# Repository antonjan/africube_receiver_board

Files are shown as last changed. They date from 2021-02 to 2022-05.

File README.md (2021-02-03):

this is an Software Define Radio receiver PCB project base on msi2500 and msi001. use kicad to view it

这是一个基于msi2500 和 msi001的软件无线电PCB工程项目， 使用kiCAD浏览此工程

如果需要PCB打样，把gerber目录下的文件发给PCB加工厂即可

Send gerbar files to PCB factory . you'd better to use SMT

建议叫工厂SMT贴片，手动焊接容易太多bug

软件使用SDRuno（选SDRPlay）

software compatible with SDRplay

使用效果

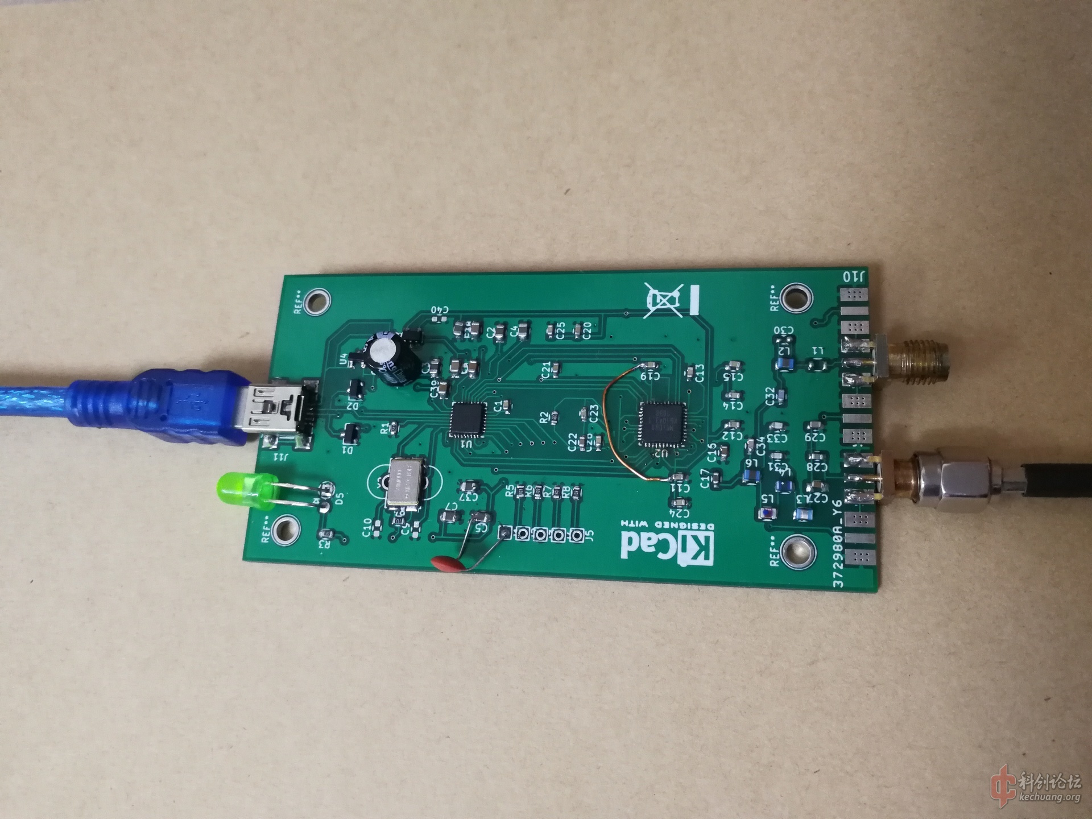
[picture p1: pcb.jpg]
PCB


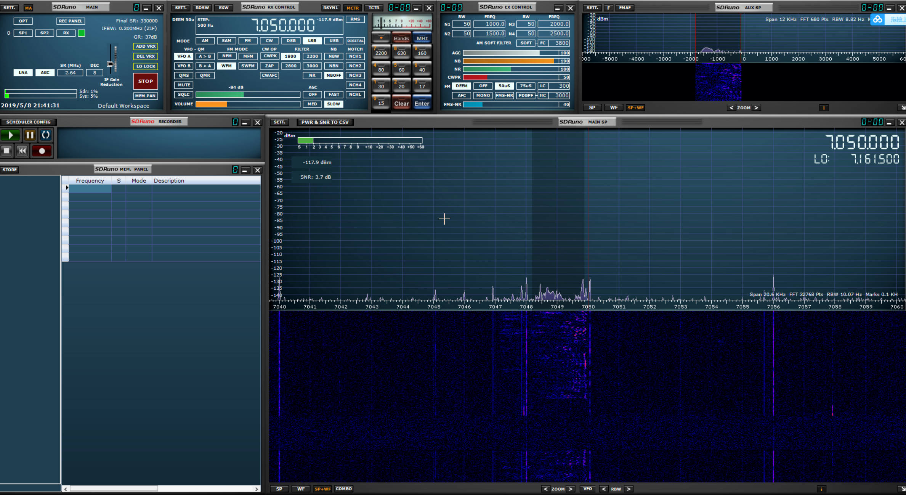
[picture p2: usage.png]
SDR


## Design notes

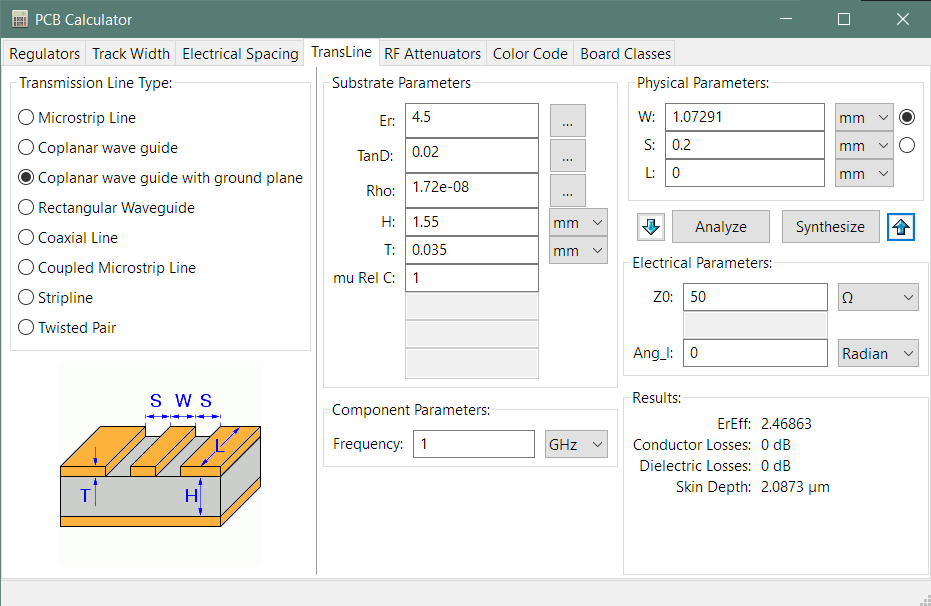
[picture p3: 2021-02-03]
msiSDR-master/Docs/Screenshot 2021-01-29 152604.png

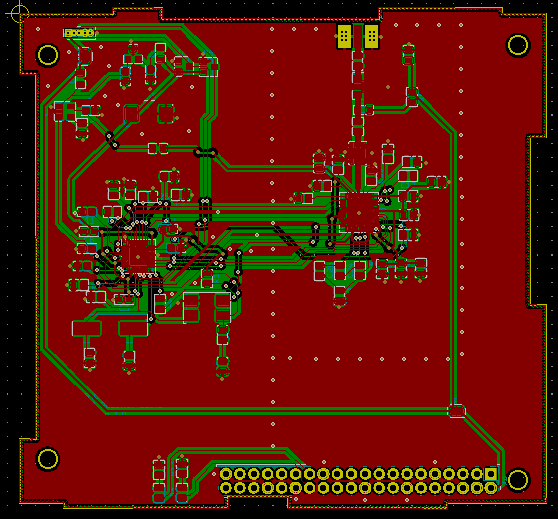
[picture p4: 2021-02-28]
Africube_rx_boards_1.png

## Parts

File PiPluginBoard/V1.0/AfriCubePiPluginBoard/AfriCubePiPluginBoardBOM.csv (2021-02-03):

Source: | F:\AfriCube\PiPluginBoard\V1.0\AfriCubePiPluginBoard\AfriCubePiPluginBoard.sch
Date: | 2020/02/01 08:34
Tool: | Eeschema (5.1.2)-2
Generator: | C:\Program Files\KiCad\bin\scripting\plugins/bom_csv_grouped_by_value.py
Component Count: | 58
Individual Components:
Item | Qty | Reference(s) | Value | LibPart | Footprint |  |  |  |  | Datasheet
 |  | BT1 | Battery_Cell_3V | Device:Battery_Cell | Battery:BatteryHolder_Keystone_3000_1x12mm |  |  |  |  | ~
 |  | C1 | 47uF | Device:C | Resistor_SMD:R_1210_3225Metric_Pad1.42x2.65mm_HandSolder |  |  |  |  | ~
 |  | C2 | 100nF | Device:C | Resistor_SMD:R_0805_2012Metric_Pad1.15x1.40mm_HandSolder |  |  |  |  | ~
 |  | C3 | 10uF | Device:C | Resistor_SMD:R_0805_2012Metric_Pad1.15x1.40mm_HandSolder |  |  |  |  | ~
 |  | C4 | 100nF | Device:C | Resistor_SMD:R_0805_2012Metric_Pad1.15x1.40mm_HandSolder |  |  |  |  | ~
 |  | C5 | 4.7uF | Device:C | Resistor_SMD:R_0805_2012Metric_Pad1.15x1.40mm_HandSolder |  |  |  |  | ~
 |  | C6 | 47uF | Device:C | Resistor_SMD:R_1210_3225Metric_Pad1.42x2.65mm_HandSolder |  |  |  |  | ~
 |  | C7 | 47uF | Device:C | Resistor_SMD:R_1210_3225Metric_Pad1.42x2.65mm_HandSolder |  |  |  |  | ~
 |  | C8 | 10uF | Device:C | Resistor_SMD:R_0805_2012Metric_Pad1.15x1.40mm_HandSolder |  |  |  |  | ~
 |  | C9 | 1uF | Device:C | Resistor_SMD:R_0805_2012Metric_Pad1.15x1.40mm_HandSolder |  |  |  |  | ~
 |  | C10 | 10uF | Device:C | Resistor_SMD:R_0805_2012Metric_Pad1.15x1.40mm_HandSolder |  |  |  |  | ~
 |  | C11 | 100nF | Device:C | Resistor_SMD:R_0805_2012Metric_Pad1.15x1.40mm_HandSolder |  |  |  |  | ~
 |  | C12 | 10uF | Device:C | Resistor_SMD:R_0805_2012Metric_Pad1.15x1.40mm_HandSolder |  |  |  |  | ~
 |  | C13 | 100nF | Device:C | Resistor_SMD:R_0805_2012Metric_Pad1.15x1.40mm_HandSolder |  |  |  |  | ~
 |  | C14 | 100nF | Device:C | Resistor_SMD:R_0805_2012Metric_Pad1.15x1.40mm_HandSolder |  |  |  |  | ~
 |  | D1 | LED | Device:LED | Resistor_SMD:R_0805_2012Metric_Pad1.15x1.40mm_HandSolder |  |  |  |  | ~
 |  | D2 | LED | Device:LED | Resistor_SMD:R_0805_2012Metric_Pad1.15x1.40mm_HandSolder |  |  |  |  | ~
 |  | D3 | BAV99 | Diode:BAV99 | Package_TO_SOT_SMD:SOT-23 |  |  |  |  | https://assets.nexperia.com/documents/data-sheet/BAV99_SER.pdf
 |  | D4 | BAV99 | Diode:BAV99 | Package_TO_SOT_SMD:SOT-23 |  |  |  |  | https://assets.nexperia.com/documents/data-sheet/BAV99_SER.pdf
 |  | J1 | USB_A | Connector:USB_A | Connector_PinHeader_1.00mm:PinHeader_1x05_P1.00mm_Vertical |  |  |  |  | ~
 |  | J2 | SD_Card | Connector:SD_Card | Connector_Card:microSD_HC_Hirose_DM3D-SF |  |  |  |  | http://portal.fciconnect.com/Comergent//fci/drawing/10067847.pdf
 |  | J3 | USB_B_Mini | Connector:USB_B_Mini | Connector_USB:USB_Mini-B_Lumberg_2486_01_Horizontal |  |  |  |  | ~
 |  | J4 | SODIMM-200 | Connector:SODIMM-200 | RaspberryPi:Conn_TE-DDR2-SODIMM-0.6-200P-doublesided
 |  | J5 | Barrel_Jack_MountingPin | Connector:Barrel_Jack_MountingPin | Connector_BarrelJack:BarrelJack_Wuerth_6941xx301002 |  |  |  |  | ~
 |  | J6 | Raspberry_Pi_2_3 | Connector:Raspberry_Pi_2_3 | Connector_PinHeader_2.54mm:PinHeader_2x20_P2.54mm_Vertical |  |  |  |  | https://www.raspberrypi.org/documentation/hardware/raspberrypi/schematics/rpi_SCH_3bplus_1p0_reduced.pdf
 |  | J7 | Conn_01x04_Male | Connector:Conn_01x04_Male | Connector_PinSocket_2.54mm:PinSocket_1x04_P2.54mm_Vertical |  |  |  |  | ~
 |  | JP1 | Jumper_Boot_Select | Jumper:Jumper_3_Open | Connector_PinSocket_2.54mm:PinSocket_1x03_P2.54mm_Vertical |  |  |  |  | ~
 |  | JP2 | WDT_S0 | Jumper:SolderJumper_3_Open | Jumper:SolderJumper-3_P1.3mm_Open_RoundedPad1.0x1.5mm |  |  |  |  | ~
 |  | JP3 | WDT_S1 | Jumper:SolderJumper_3_Open | Jumper:SolderJumper-3_P1.3mm_Open_RoundedPad1.0x1.5mm |  |  |  |  | ~
 |  | JP4 | WDT_S2 | Jumper:SolderJumper_3_Open | Jumper:SolderJumper-3_P1.3mm_Open_RoundedPad1.0x1.5mm |  |  |  |  | ~
 |  | P1 | PC104 | AfriCubePiPluginBoard-rescue:PC104-PC104 | PC104B:PC104
 |  | Q1 | BSS138 | Transistor_FET:BSS138 | Package_TO_SOT_SMD:SOT-23 |  |  |  |  | https://www.fairchildsemi.com/datasheets/BS/BSS138.pdf
 |  | Q2 | BSS138 | Transistor_FET:BSS138 | Package_TO_SOT_SMD:SOT-23 |  |  |  |  | https://www.fairchildsemi.com/datasheets/BS/BSS138.pdf
 |  | Q3 | BSS138 | Transistor_FET:BSS138 | Package_TO_SOT_SMD:SOT-23 |  |  |  |  | https://www.fairchildsemi.com/datasheets/BS/BSS138.pdf
 |  | R1 | 47K | Device:R | Resistor_SMD:R_0805_2012Metric_Pad1.15x1.40mm_HandSolder |  |  |  |  | ~
 |  | R2 | 470R | Device:R | Resistor_SMD:R_0805_2012Metric_Pad1.15x1.40mm_HandSolder |  |  |  |  | ~
 |  | R3 | 47K | Device:R | Resistor_SMD:R_0805_2012Metric_Pad1.15x1.40mm_HandSolder |  |  |  |  | ~
 |  | R4 | 100K | Device:R | Resistor_SMD:R_0805_2012Metric_Pad1.15x1.40mm_HandSolder |  |  |  |  | ~
 |  | R5 | 100K | Device:R | Resistor_SMD:R_0805_2012Metric_Pad1.15x1.40mm_HandSolder |  |  |  |  | ~
 |  | R6 | 47K | Device:R | Resistor_SMD:R_0805_2012Metric_Pad1.15x1.40mm_HandSolder |  |  |  |  | ~
 |  | R7 | 470R | Device:R | Resistor_SMD:R_0805_2012Metric_Pad1.15x1.40mm_HandSolder |  |  |  |  | ~
 |  | R8 | 100K | Device:R | Resistor_SMD:R_0805_2012Metric_Pad1.15x1.40mm_HandSolder |  |  |  |  | ~
 |  | R9 | 100K | Device:R | Resistor_SMD:R_0805_2012Metric_Pad1.15x1.40mm_HandSolder |  |  |  |  | ~
 |  | R10 | 100K | Device:R | Resistor_SMD:R_0805_2012Metric_Pad1.15x1.40mm_HandSolder |  |  |  |  | ~
 |  | R11 | 100K | Device:R | Resistor_SMD:R_0805_2012Metric_Pad1.15x1.40mm_HandSolder |  |  |  |  | ~
 |  | R12 | 4K7 | Device:R | Resistor_SMD:R_0805_2012Metric_Pad1.15x1.40mm_HandSolder |  |  |  |  | ~
 |  | R13 | 4K7 | Device:R | Resistor_SMD:R_0805_2012Metric_Pad1.15x1.40mm_HandSolder |  |  |  |  | ~
 |  | R14 | 100K | Device:R | Resistor_SMD:R_0805_2012Metric_Pad1.15x1.40mm_HandSolder |  |  |  |  | ~
 |  | R15 | 100K | Device:R | Resistor_SMD:R_0805_2012Metric_Pad1.15x1.40mm_HandSolder |  |  |  |  | ~
 |  | R16 | 100K | Device:R | Resistor_SMD:R_0805_2012Metric_Pad1.15x1.40mm_HandSolder |  |  |  |  | ~
 |  | R17 | 270R | Device:R | Resistor_SMD:R_0805_2012Metric_Pad1.15x1.40mm_HandSolder |  |  |  |  | ~
 |  | R18 | 150R | Device:R | Resistor_SMD:R_0805_2012Metric_Pad1.15x1.40mm_HandSolder |  |  |  |  | ~
 |  | R19 | 270R | Device:R | Resistor_SMD:R_0805_2012Metric_Pad1.15x1.40mm_HandSolder |  |  |  |  | ~
 |  | R20 | 150R | Device:R | Resistor_SMD:R_0805_2012Metric_Pad1.15x1.40mm_HandSolder |  |  |  |  | ~
 |  | U1 | FSUSB42MUX | AfriCubePiPluginBoard-rescue:FSUSB42MUX-FSUSB42MUX | Package_SO:MSOP-10_3x3mm_P0.5mm
 |  | U2 | TLV70218_SOT23-5 | Regulator_Linear:TLV70218_SOT23-5 | Package_TO_SOT_SMD:SOT-23-5 |  |  |  |  | http://www.ti.com/lit/ds/symlink/tlv702.pdf
 |  | U3 | MAX6373 | Power_Supervisor:MAX6373 | Package_TO_SOT_SMD:SOT-23-8 |  |  |  |  | https://datasheets.maximintegrated.com/en/ds/MAX6369-MAX6374.pdf
 |  | U4 | DS3231M | Timer_RTC:DS3231M | Package_SO:SOIC-16W_7.5x10.3mm_P1.27mm |  |  |  |  | http://datasheets.maximintegrated.com/en/ds/DS3231.pdf
Collated Components:
Item | Qty | Reference(s) | Value | LibPart | Footprint | Req | Have | Ordered from RS | RS part nr | Datasheet
1 | 1 | BT1 | Battery_Cell_3V | Device:Battery_Cell | Battery:BatteryHolder_Keystone_3000_1x12mm | 3 | 0 | 5 | 219-7926 | ~
2 | 3 | C1, C6, C7 | 47uF (max 5V) | Device:C | Resistor_SMD:R_1210_3225Metric_Pad1.42x2.65mm_HandSolder | 9 | 1 | 10 | 788-3029/891-9817 | ~
3 | 5 | C2, C4, C11, C13, C14 | 100nF | Device:C | Resistor_SMD:R_0805_2012Metric_Pad1.15x1.40mm_HandSolder | 15 | 25 | 0 | 264-4416 | ~
4 | 4 | C3, C8, C10, C12 | 10uF (1xmax13.5V, others max 3V3) | Device:C | Resistor_SMD:R_0805_2012Metric_Pad1.15x1.40mm_HandSolder | 12 | 25+ | 0 | 723-6039 | ~
5 | 1 | C5 | 4.7uF (max 3v3) | Device:C | Resistor_SMD:R_0805_2012Metric_Pad1.15x1.40mm_HandSolder | 3 | 0 | 10 | 152-6136 | ~
6 | 1 | C9 | 1uF (max 3V) | Device:C | Resistor_SMD:R_0805_2012Metric_Pad1.15x1.40mm_HandSolder | 3 | 10 | 0 | 451-5770 | ~
7 | 2 | D1, D2 | LED | Device:LED | Resistor_SMD:R_0805_2012Metric_Pad1.15x1.40mm_HandSolder | 6 |  |  |  | ~
8 | 2 | D3, D4 | BAV99 | Diode:BAV99 | Package_TO_SOT_SMD:SOT-23 | 6 |  |  |  | https://assets.nexperia.com/documents/data-sheet/BAV99_SER.pdf
9 | 1 | J1 | USB_A | Connector:USB_A | Connector_PinHeader_1.00mm:PinHeader_1x05_P1.00mm_Vertical | 3 |  |  |  | ~
10 | 1 | J2 | SD_Card | Connector:SD_Card | Connector_Card:microSD_HC_Hirose_DM3D-SF | 3 |  |  |  | http://portal.fciconnect.com/Comergent//fci/drawing/10067847.pdf
11 | 1 | J3 | USB_B_Mini | Connector:USB_B_Mini | Connector_USB:USB_Mini-B_Lumberg_2486_01_Horizontal | 3 |  |  |  | ~
12 | 1 | J4 | SODIMM-200 | Connector:SODIMM-200 | RaspberryPi:Conn_TE-DDR2-SODIMM-0.6-200P-doublesided | 3
13 | 1 | J5 | Barrel_Jack_MountingPin | Connector:Barrel_Jack_MountingPin | Connector_BarrelJack:BarrelJack_Wuerth_6941xx301002 | 3 | 0 | 5 |  | ~
14 | 1 | J6 | Raspberry_Pi_2_3 | Connector:Raspberry_Pi_2_3 | Connector_PinHeader_2.54mm:PinHeader_2x20_P2.54mm_Vertical | 3 | 0 |  |  | https://www.raspberrypi.org/documentation/hardware/raspberrypi/schematics/rpi_SCH_3bplus_1p0_reduced.pdf
15 | 1 | J7 | Conn_01x04_Male | Connector:Conn_01x04_Male | Connector_PinSocket_2.54mm:PinSocket_1x04_P2.54mm_Vertical | 3 | many | 0 |  | ~
16 | 1 | JP1 | Jumper_Boot_Select | Jumper:Jumper_3_Open | Connector_PinSocket_2.54mm:PinSocket_1x03_P2.54mm_Vertical | 3 | many | 0 |  | ~
17 | 1 | JP2 | WDT_S0 | Jumper:SolderJumper_3_Open | Jumper:SolderJumper-3_P1.3mm_Open_RoundedPad1.0x1.5mm | 3 | NR |  |  | ~
18 | 1 | JP3 | WDT_S1 | Jumper:SolderJumper_3_Open | Jumper:SolderJumper-3_P1.3mm_Open_RoundedPad1.0x1.5mm | 3 | NR |  |  | ~
19 | 1 | JP4 | WDT_S2 | Jumper:SolderJumper_3_Open | Jumper:SolderJumper-3_P1.3mm_Open_RoundedPad1.0x1.5mm | 3 | NR |  |  | ~
20 | 1 | P1 | PC104 | AfriCubePiPluginBoard-rescue:PC104-PC104 | PC104B:PC104 | 3 | 2.5
21 | 3 | Q1, Q2, Q3 | BSS138 | Transistor_FET:BSS138 | Package_TO_SOT_SMD:SOT-23 | 9 |  |  |  | https://www.fairchildsemi.com/datasheets/BS/BSS138.pdf
22 | 3 | R1, R3, R6 | 47K | Device:R | Resistor_SMD:R_0805_2012Metric_Pad1.15x1.40mm_HandSolder | 9 |  |  |  | ~
23 | 2 | R2, R7 | 470R | Device:R | Resistor_SMD:R_0805_2012Metric_Pad1.15x1.40mm_HandSolder | 6 |  |  |  | ~
24 | 9 | R4, R5, R8, R9, R10, R11, R14, R15, R16 | 100K | Device:R | Resistor_SMD:R_0805_2012Metric_Pad1.15x1.40mm_HandSolder | 27 |  |  |  | ~
25 | 2 | R12, R13 | 4K7 | Device:R | Resistor_SMD:R_0805_2012Metric_Pad1.15x1.40mm_HandSolder | 6 |  |  |  | ~
26 | 2 | R17, R19 | 270R | Device:R | Resistor_SMD:R_0805_2012Metric_Pad1.15x1.40mm_HandSolder | 6 |  |  |  | ~
27 | 2 | R18, R20 | 150R | Device:R | Resistor_SMD:R_0805_2012Metric_Pad1.15x1.40mm_HandSolder | 6 |  |  |  | ~
28 | 1 | U1 | FSUSB42MUX | AfriCubePiPluginBoard-rescue:FSUSB42MUX-FSUSB42MUX | Package_SO:MSOP-10_3x3mm_P0.5mm | 3 | 0 | 3
29 | 1 | U2 | TLV70218_SOT23-5 | Regulator_Linear:TLV70218_SOT23-5 | Package_TO_SOT_SMD:SOT-23-5 | 3 |  |  |  | http://www.ti.com/lit/ds/symlink/tlv702.pdf
30 | 1 | U3 | MAX6373 | Power_Supervisor:MAX6373 | Package_TO_SOT_SMD:SOT-23-8 | 3 |  |  |  | https://datasheets.maximintegrated.com/en/ds/MAX6369-MAX6374.pdf
31 | 1 | U4 | DS3231M | Timer_RTC:DS3231M | Package_SO:SOIC-16W_7.5x10.3mm_P1.27mm | 3 |  |  |  | http://datasheets.maximintegrated.com/en/ds/DS3231.pdf

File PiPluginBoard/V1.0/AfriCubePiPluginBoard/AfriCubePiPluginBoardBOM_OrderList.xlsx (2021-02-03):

Source: | F:\AfriCube\PiPluginBoard\V1.0\AfriCubePiPluginBoard\AfriCubePiPluginBoard.sch
Date: | 2020-02-01 08:34
Tool: | Eeschema (5.1.2)-2
Generator: | C:\Program Files\KiCad\bin\scripting\plugins/bom_csv_grouped_by_value.py
Component Count: | 58
Individual Components:
Item | Qty | Reference(s) | Value | LibPart | Footprint |  |  |  |  | Datasheet
 |  | BT1 | Battery_Cell_3V | Device:Battery_Cell | Battery:BatteryHolder_Keystone_3000_1x12mm |  |  |  |  | ~
 |  | C1 | 47uF | Device:C | Resistor_SMD:R_1210_3225Metric_Pad1.42x2.65mm_HandSolder |  |  |  |  | ~
 |  | C2 | 100nF | Device:C | Resistor_SMD:R_0805_2012Metric_Pad1.15x1.40mm_HandSolder |  |  |  |  | ~
 |  | C3 | 10uF | Device:C | Resistor_SMD:R_0805_2012Metric_Pad1.15x1.40mm_HandSolder |  |  |  |  | ~
 |  | C4 | 100nF | Device:C | Resistor_SMD:R_0805_2012Metric_Pad1.15x1.40mm_HandSolder |  |  |  |  | ~
 |  | C5 | 4.7uF | Device:C | Resistor_SMD:R_0805_2012Metric_Pad1.15x1.40mm_HandSolder |  |  |  |  | ~
 |  | C6 | 47uF | Device:C | Resistor_SMD:R_1210_3225Metric_Pad1.42x2.65mm_HandSolder |  |  |  |  | ~
 |  | C7 | 47uF | Device:C | Resistor_SMD:R_1210_3225Metric_Pad1.42x2.65mm_HandSolder |  |  |  |  | ~
 |  | C8 | 10uF | Device:C | Resistor_SMD:R_0805_2012Metric_Pad1.15x1.40mm_HandSolder |  |  |  |  | ~
 |  | C9 | 1uF | Device:C | Resistor_SMD:R_0805_2012Metric_Pad1.15x1.40mm_HandSolder |  |  |  |  | ~
 |  | C10 | 10uF | Device:C | Resistor_SMD:R_0805_2012Metric_Pad1.15x1.40mm_HandSolder |  |  |  |  | ~
 |  | C11 | 100nF | Device:C | Resistor_SMD:R_0805_2012Metric_Pad1.15x1.40mm_HandSolder |  |  |  |  | ~
 |  | C12 | 10uF | Device:C | Resistor_SMD:R_0805_2012Metric_Pad1.15x1.40mm_HandSolder |  |  |  |  | ~
 |  | C13 | 100nF | Device:C | Resistor_SMD:R_0805_2012Metric_Pad1.15x1.40mm_HandSolder |  |  |  |  | ~
 |  | C14 | 100nF | Device:C | Resistor_SMD:R_0805_2012Metric_Pad1.15x1.40mm_HandSolder |  |  |  |  | ~
 |  | D1 | LED | Device:LED | Resistor_SMD:R_0805_2012Metric_Pad1.15x1.40mm_HandSolder |  |  |  |  | ~
 |  | D2 | LED | Device:LED | Resistor_SMD:R_0805_2012Metric_Pad1.15x1.40mm_HandSolder |  |  |  |  | ~
 |  | D3 | BAV99 | Diode:BAV99 | Package_TO_SOT_SMD:SOT-23 |  |  |  |  | https://assets.nexperia.com/documents/data-sheet/BAV99_SER.pdf
 |  | D4 | BAV99 | Diode:BAV99 | Package_TO_SOT_SMD:SOT-23 |  |  |  |  | https://assets.nexperia.com/documents/data-sheet/BAV99_SER.pdf
 |  | J1 | USB_A | Connector:USB_A | Connector_PinHeader_1.00mm:PinHeader_1x05_P1.00mm_Vertical |  |  |  |  | ~
 |  | J2 | SD_Card | Connector:SD_Card | Connector_Card:microSD_HC_Hirose_DM3D-SF |  |  |  |  | http://portal.fciconnect.com/Comergent//fci/drawing/10067847.pdf
 |  | J3 | USB_B_Mini | Connector:USB_B_Mini | Connector_USB:USB_Mini-B_Lumberg_2486_01_Horizontal |  |  |  |  | ~
 |  | J4 | SODIMM-200 | Connector:SODIMM-200 | RaspberryPi:Conn_TE-DDR2-SODIMM-0.6-200P-doublesided
 |  | J5 | Barrel_Jack_MountingPin | Connector:Barrel_Jack_MountingPin | Connector_BarrelJack:BarrelJack_Wuerth_6941xx301002 |  |  |  |  | ~
 |  | J6 | Raspberry_Pi_2_3 | Connector:Raspberry_Pi_2_3 | Connector_PinHeader_2.54mm:PinHeader_2x20_P2.54mm_Vertical |  |  |  |  | https://www.raspberrypi.org/documentation/hardware/raspberrypi/schematics/rpi_SCH_3bplus_1p0_reduced.pdf
 |  | J7 | Conn_01x04_Male | Connector:Conn_01x04_Male | Connector_PinSocket_2.54mm:PinSocket_1x04_P2.54mm_Vertical |  |  |  |  | ~
 |  | JP1 | Jumper_Boot_Select | Jumper:Jumper_3_Open | Connector_PinSocket_2.54mm:PinSocket_1x03_P2.54mm_Vertical |  |  |  |  | ~
 |  | JP2 | WDT_S0 | Jumper:SolderJumper_3_Open | Jumper:SolderJumper-3_P1.3mm_Open_RoundedPad1.0x1.5mm |  |  |  |  | ~
 |  | JP3 | WDT_S1 | Jumper:SolderJumper_3_Open | Jumper:SolderJumper-3_P1.3mm_Open_RoundedPad1.0x1.5mm |  |  |  |  | ~
 |  | JP4 | WDT_S2 | Jumper:SolderJumper_3_Open | Jumper:SolderJumper-3_P1.3mm_Open_RoundedPad1.0x1.5mm |  |  |  |  | ~
 |  | P1 | PC104 | AfriCubePiPluginBoard-rescue:PC104-PC104 | PC104B:PC104
 |  | Q1 | BSS138 | Transistor_FET:BSS138 | Package_TO_SOT_SMD:SOT-23 |  |  |  |  | https://www.fairchildsemi.com/datasheets/BS/BSS138.pdf
 |  | Q2 | BSS138 | Transistor_FET:BSS138 | Package_TO_SOT_SMD:SOT-23 |  |  |  |  | https://www.fairchildsemi.com/datasheets/BS/BSS138.pdf
 |  | Q3 | BSS138 | Transistor_FET:BSS138 | Package_TO_SOT_SMD:SOT-23 |  |  |  |  | https://www.fairchildsemi.com/datasheets/BS/BSS138.pdf
 |  | R 1 | 47K | Device:R | Resistor_SMD:R_0805_2012Metric_Pad1.15x1.40mm_HandSolder |  |  |  |  | ~
 |  | R 2 | 470R | Device:R | Resistor_SMD:R_0805_2012Metric_Pad1.15x1.40mm_HandSolder |  |  |  |  | ~
 |  | R 3 | 47K | Device:R | Resistor_SMD:R_0805_2012Metric_Pad1.15x1.40mm_HandSolder |  |  |  |  | ~
 |  | R 4 | 100K | Device:R | Resistor_SMD:R_0805_2012Metric_Pad1.15x1.40mm_HandSolder |  |  |  |  | ~
 |  | R 5 | 100K | Device:R | Resistor_SMD:R_0805_2012Metric_Pad1.15x1.40mm_HandSolder |  |  |  |  | ~
 |  | R 6 | 47K | Device:R | Resistor_SMD:R_0805_2012Metric_Pad1.15x1.40mm_HandSolder |  |  |  |  | ~
 |  | R 7 | 470R | Device:R | Resistor_SMD:R_0805_2012Metric_Pad1.15x1.40mm_HandSolder |  |  |  |  | ~
 |  | R 8 | 100K | Device:R | Resistor_SMD:R_0805_2012Metric_Pad1.15x1.40mm_HandSolder |  |  |  |  | ~
 |  | R 9 | 100K | Device:R | Resistor_SMD:R_0805_2012Metric_Pad1.15x1.40mm_HandSolder |  |  |  |  | ~
 |  | R 10 | 100K | Device:R | Resistor_SMD:R_0805_2012Metric_Pad1.15x1.40mm_HandSolder |  |  |  |  | ~
 |  | R 11 | 100K | Device:R | Resistor_SMD:R_0805_2012Metric_Pad1.15x1.40mm_HandSolder |  |  |  |  | ~
 |  | R 12 | 4K7 | Device:R | Resistor_SMD:R_0805_2012Metric_Pad1.15x1.40mm_HandSolder |  |  |  |  | ~
 |  | R 13 | 4K7 | Device:R | Resistor_SMD:R_0805_2012Metric_Pad1.15x1.40mm_HandSolder |  |  |  |  | ~
 |  | R 14 | 100K | Device:R | Resistor_SMD:R_0805_2012Metric_Pad1.15x1.40mm_HandSolder |  |  |  |  | ~
 |  | R 15 | 100K | Device:R | Resistor_SMD:R_0805_2012Metric_Pad1.15x1.40mm_HandSolder |  |  |  |  | ~
 |  | R 16 | 100K | Device:R | Resistor_SMD:R_0805_2012Metric_Pad1.15x1.40mm_HandSolder |  |  |  |  | ~
 |  | R 17 | 270R | Device:R | Resistor_SMD:R_0805_2012Metric_Pad1.15x1.40mm_HandSolder |  |  |  |  | ~
 |  | R 18 | 150R | Device:R | Resistor_SMD:R_0805_2012Metric_Pad1.15x1.40mm_HandSolder |  |  |  |  | ~
 |  | R 19 | 270R | Device:R | Resistor_SMD:R_0805_2012Metric_Pad1.15x1.40mm_HandSolder |  |  |  |  | ~
 |  | R 20 | 150R | Device:R | Resistor_SMD:R_0805_2012Metric_Pad1.15x1.40mm_HandSolder |  |  |  |  | ~
 |  | U1 | FSUSB42MUX | AfriCubePiPluginBoard-rescue:FSUSB42MUX-FSUSB42MUX | Package_SO:MSOP-10_3x3mm_P0.5mm
 |  | U2 | TLV70218_SOT23-5 | Regulator_Linear:TLV70218_SOT23-5 | Package_TO_SOT_SMD:SOT-23-5 |  |  |  |  | http://www.ti.com/lit/ds/symlink/tlv702.pdf
 |  | U3 | MAX6373 | Power_Supervisor:MAX6373 | Package_TO_SOT_SMD:SOT-23-8 |  |  |  |  | https://datasheets.maximintegrated.com/en/ds/MAX6369-MAX6374.pdf
 |  | U4 | DS3231M | Timer_RTC:DS3231M | Package_SO:SOIC-16W_7.5x10.3mm_P1.27mm |  |  |  |  | http://datasheets.maximintegrated.com/en/ds/DS3231.pdf
Collated Components:
Item | Qty | Reference(s) | Value | LibPart | Footprint | Req | Have | Ordered from RS | RS part nr | Datasheet
1 | 1 | BT1 | Battery_Cell_3V | Device:Battery_Cell | Battery:BatteryHolder_Keystone_3000_1x12mm | 3 | 0 | 5 | 219-7926 | ~
2 | 3 | C1, C6, C7 | 47uF (max 5V) | Device:C | Resistor_SMD:R_1210_3225Metric_Pad1.42x2.65mm_HandSolder | 9 | 1 | 10 | 788-3029/891-9817 | ~
3 | 5 | C2, C4, C11, C13, C14 | 100nF | Device:C | Resistor_SMD:R_0805_2012Metric_Pad1.15x1.40mm_HandSolder | 15 | 25 | 0 | 264-4416 | ~
4 | 4 | C3, C8, C10, C12 | 10uF (1xmax13.5V, others max 3V3) | Device:C | Resistor_SMD:R_0805_2012Metric_Pad1.15x1.40mm_HandSolder | 12 | 25+ | 0 | 723-6039 | ~
5 | 1 | C5 | 4.7uF (max 3v3) | Device:C | Resistor_SMD:R_0805_2012Metric_Pad1.15x1.40mm_HandSolder | 3 | 0 | 10 | 152-6136 | ~
6 | 1 | C9 | 1uF (max 3V) | Device:C | Resistor_SMD:R_0805_2012Metric_Pad1.15x1.40mm_HandSolder | 3 | 10 | 0 | 451-5770 | ~
7 | 2 | D1, D2 | LED | Device:LED | Resistor_SMD:R_0805_2012Metric_Pad1.15x1.40mm_HandSolder | 6 | many | 0 | 692-0929 | ~
8 | 2 | D3, D4 | BAV99 | Diode:BAV99 | Package_TO_SOT_SMD:SOT-23 | 6 | 0 | 25 | 690-0016 | https://assets.nexperia.com/documents/data-sheet/BAV99_SER.pdf
9 | 1 | J1 | USB_A | Connector:USB_A | Connector_PinHeader_1.00mm:PinHeader_1x05_P1.00mm_Vertical | 3 | many | 0 |  | ~
10 | 1 | J2 | SD_Card | Connector:SD_Card | Connector_Card:microSD_HC_Hirose_DM3D-SF | 3 | 0 | 5 | 738-8809 | http://portal.fciconnect.com/Comergent//fci/drawing/10067847.pdf
11 | 1 | J3 | USB_B_Mini | Connector:USB_B_Mini | Connector_USB:USB_Mini-B_Lumberg_2486_01_Horizontal | 3 | 0 | 5 | 666-1099 | ~
12 | 1 | J4 | SODIMM-200 | Connector:SODIMM-200 | RaspberryPi:Conn_TE-DDR2-SODIMM-0.6-200P-doublesided | 3 | 4 | 0 (combine 12x2s ) | 670-3500
13 | 1 | J5 | Barrel_Jack_MountingPin | Connector:Barrel_Jack_MountingPin | Connector_BarrelJack:BarrelJack_Wuerth_6941xx301002 | 3 | 0 | 5 | 122-4879 | ~
14 | 1 | J6 | Raspberry_Pi_2_3 | Connector:Raspberry_Pi_2_3 | Connector_PinHeader_2.54mm:PinHeader_2x20_P2.54mm_Vertical | 3 | 0 | 5 | 670-3496 | https://www.raspberrypi.org/documentation/hardware/raspberrypi/schematics/rpi_SCH_3bplus_1p0_reduced.pdf
15 | 1 | J7 | Conn_01x04_Male | Connector:Conn_01x04_Male | Connector_PinSocket_2.54mm:PinSocket_1x04_P2.54mm_Vertical | 3 | many | 0 |  | ~
16 | 1 | JP1 | Jumper_Boot_Select | Jumper:Jumper_3_Open | Connector_PinSocket_2.54mm:PinSocket_1x03_P2.54mm_Vertical | 3 | many | 0 |  | ~
17 | 1 | JP2 | WDT_S0 | Jumper:SolderJumper_3_Open | Jumper:SolderJumper-3_P1.3mm_Open_RoundedPad1.0x1.5mm | 3 | NR | 0 |  | ~
18 | 1 | JP3 | WDT_S1 | Jumper:SolderJumper_3_Open | Jumper:SolderJumper-3_P1.3mm_Open_RoundedPad1.0x1.5mm | 3 | NR | 0 |  | ~
19 | 1 | JP4 | WDT_S2 | Jumper:SolderJumper_3_Open | Jumper:SolderJumper-3_P1.3mm_Open_RoundedPad1.0x1.5mm | 3 | NR | 0 |  | ~
20 | 1 | P1 | PC104 | AfriCubePiPluginBoard-rescue:PC104-PC104 | PC104B:PC104 | 3 | 2.5 | 1 short!
21 | 3 | Q1, Q2, Q3 | BSS138 | Transistor_FET:BSS138 | Package_TO_SOT_SMD:SOT-23 | 9 | 5 | 10 | 671-0324 | https://www.fairchildsemi.com/datasheets/BS/BSS138.pdf
22 | 3 | R1, R3, R6 | 47K | Device:R | Resistor_SMD:R_0805_2012Metric_Pad1.15x1.40mm_HandSolder | 9 | 0 | 50 | 679-1434 | ~
23 | 2 | R2, R7 | 470R | Device:R | Resistor_SMD:R_0805_2012Metric_Pad1.15x1.40mm_HandSolder | 6 | 0 | 25 | 812-3546 | ~
24 | 9 | R4, R5, R8, R9, R10, R11, R14, R15, R16 | 100K | Device:R | Resistor_SMD:R_0805_2012Metric_Pad1.15x1.40mm_HandSolder | 27 | many | 0 | 223-0691 | ~
25 | 2 | R12, R13 | 4K7 | Device:R | Resistor_SMD:R_0805_2012Metric_Pad1.15x1.40mm_HandSolder | 6 | many | 0 | 223-0528 | ~
26 | 2 | R17, R19 | 270R | Device:R | Resistor_SMD:R_0805_2012Metric_Pad1.15x1.40mm_HandSolder | 6 | 0 | 50 | 679-1169 | ~
27 | 2 | R18, R20 | 150R | Device:R | Resistor_SMD:R_0805_2012Metric_Pad1.15x1.40mm_HandSolder | 6 | 0 | 50 | 223-0310 | ~
28 | 1 | U1 | FSUSB42MUX | AfriCubePiPluginBoard-rescue:FSUSB42MUX-FSUSB42MUX | Package_SO:MSOP-10_3x3mm_P0.5mm | 3 | 0 | 3 | 739-5144
29 | 1 | U2 | TLV70218_SOT23-5 | Regulator_Linear:TLV70218_SOT23-5 | Package_TO_SOT_SMD:SOT-23-5 | 3 | 0 | 10 | 825-3700 | http://www.ti.com/lit/ds/symlink/tlv702.pdf
30 | 1 | U3 | MAX6373 | Power_Supervisor:MAX6373 | Package_TO_SOT_SMD:SOT-23-8 | 3 | 0 | 4 | 783-3618 | https://datasheets.maximintegrated.com/en/ds/MAX6369-MAX6374.pdf
31 | 1 | U4 | DS3231M | Timer_RTC:DS3231M | Package_SO:SOIC-16W_7.5x10.3mm_P1.27mm | 3 | 0 | 3 | 191-3543 | http://datasheets.maximintegrated.com/en/ds/DS3231.pdf

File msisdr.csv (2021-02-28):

Id | Designator | Package | Quantity | Designation | Supplier and ref
1 | L4,L3,L2 | L_0805_2012Metric | 3 | L
2 | U3 | QFN-40-1EP_6x6mm_P0.5mm_EP4.6x4.6mm | 1 | msi001
3 | U4 | SOT-23-5 | 1 | RT9193-28
4 | U5 | SOT-23 | 1 | AP7313-33SAG
5 | Y2 | Crystal_SMD_HC49-SD | 1 | 24MHz
6 | U1 | QFN-32-1EP_5x5mm_P0.5mm_EP3.1x3.1mm | 1 | msi2500
7 | Y1 | Crystal_SMD_7050-4Pin_7.0x5.0mm | 1 | 24MHZ
8 | C28,C31,C29,C27,C25,C23,C22,C16,C15,C7,C5,C30,C32 | C_0805_2012Metric | 13 | 10nF
9 | R10,R8,R11 | R_0805_2012Metric | 3 | 50
10 | R9 | R_0805_2012Metric | 1 | 390
11 | R7,R6,R5,R4,R1 | R_0805_2012Metric | 5 | 10K
12 | R3 | R_0805_2012Metric | 1 | 510R
13 | R2 | R_0805_2012Metric | 1 | 512
14 | C26 | C_0805_2012Metric | 1 | 33nF
15 | C24 | C_0805_2012Metric | 1 | 6800pF
16 | C21,C20,C18 | C_0805_2012Metric | 3 | 1nF
17 | C19,C17 | C_0805_2012Metric | 2 | 100nF
18 | C14 | C_0805_2012Metric | 1 | 1uF
19 | C9,C2 | C_0805_2012Metric | 2 | 1UF
20 | C6,C4 | C_0805_2012Metric | 2 | 15pF
21 | D1,D2,D3 | LED_0805_2012Metric | 3 | LED
22 | U2 | DFN-6-1EP_3x3mm_P1mm_EP1.5x2.4mm | 1 | B39431B3710U410
23 | C1,C3,C8,C10,C11,C12,C13 | CP_EIA-2012-12_Kemet-R | 7 | CP
24 | C33,C36,C37 | CP_EIA-2012-12_Kemet-R | 3 | 10uF
25 | D4,D5 | SOT-23 | 2 | BAV99LT1G
26 | J1 | SMA_OPL_EMPTYHEAD | 1 | SMA_UHF
27 | J2 | PinHeader_2x20_P2.54mm_Vertical | 1 | Raspberry_Pi_2_3
28 | J3 | PinHeader_1x05_P1.00mm_Vertical | 1 | USB_OTG
29 | C34 | C_0805_2012Metric | 1 | 22nF
30 | C35 | CP_EIA-7343-15_Kemet-W | 1 | 100uF
31 | R12,R13 | R_0805_2012Metric | 2 | 470
32 | U6 | SOT-89-3 | 1 | PGA-103
33 | L1 | L_0805_2012Metric | 1 | 330nH
34 | JP1 | SolderJumper-2_P1.3mm_Bridged_RoundedPad1.0x1.5mm | 1 | 5V Pi
35 | JP2 | SolderJumper-2_P1.3mm_Open_RoundedPad1.0x1.5mm | 1 | 5V USB

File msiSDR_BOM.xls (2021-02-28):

Mfr Part Number (Input) | Manufacturer Part Number | Mouser Part Number | Manufacturer Name | Description | Quantity 1 | Unit Price 1 | Quantity 2 | Unit Price 2 | Quantity 3 | Unit Price 3 | Quantity 4 | Unit Price 4 | Quantity 5 | Unit Price 5 | Order Quantity | Order Unit Price | Min./Mult. | Availability | Lead Time in Days | Lifecycle | NCNR | RoHS | Pb Free | Package Type | Datasheet URL | Product Image | Design Risk
 | msi001
 | RT9193-28
 | AP7313-33SAG
 | C0805C103J4RECAUTO7210 |  |  |  | 13
 | 50 |  |  |  | 3
 | RCS0805390RFKEA |  |  |  | 1
 | CRCW080510K0FKEAC |  |  |  | 5
 | CRCW0805510RFKEA |  |  |  | 2
 | C0805C333M4REC7210 |  |  |  | 1
 | C0805C682K4HACTU |  |  |  | 1
 | C0805C102K4HACTU |  |  |  | 3
 | C0805X104K4RACAUTO |  |  |  | 2
 | C0805T105K4RACTU |  |  |  | 3
 | L1210R150MDWIT |  |  |  | 3
 | C0805C150G4HACTU |  |  |  | 2
 | LTW-170TK |  |  |  | 3
 | B39431B3710U410 |  |  |  | 1
 | CP |  |  |  | 7
 | C0805C106K4PAC7210 |  |  |  | 3
 | BAV99LT1G |  |  |  | 2
 | SMA_UHF
 | Raspberry_Pi_2_3
 | USB_OTG
 | C0805C223J4RACTU |  |  |  | 1
 | TAJY107M016RNJ |  |  |  | 1
 | CRCW0805470RFKEA |  |  |  | 2
 | PGA-103 |  |  |  | 1
 | CE201210-R33J |  |  |  | 1
 | 22-28-4200
 | 2223

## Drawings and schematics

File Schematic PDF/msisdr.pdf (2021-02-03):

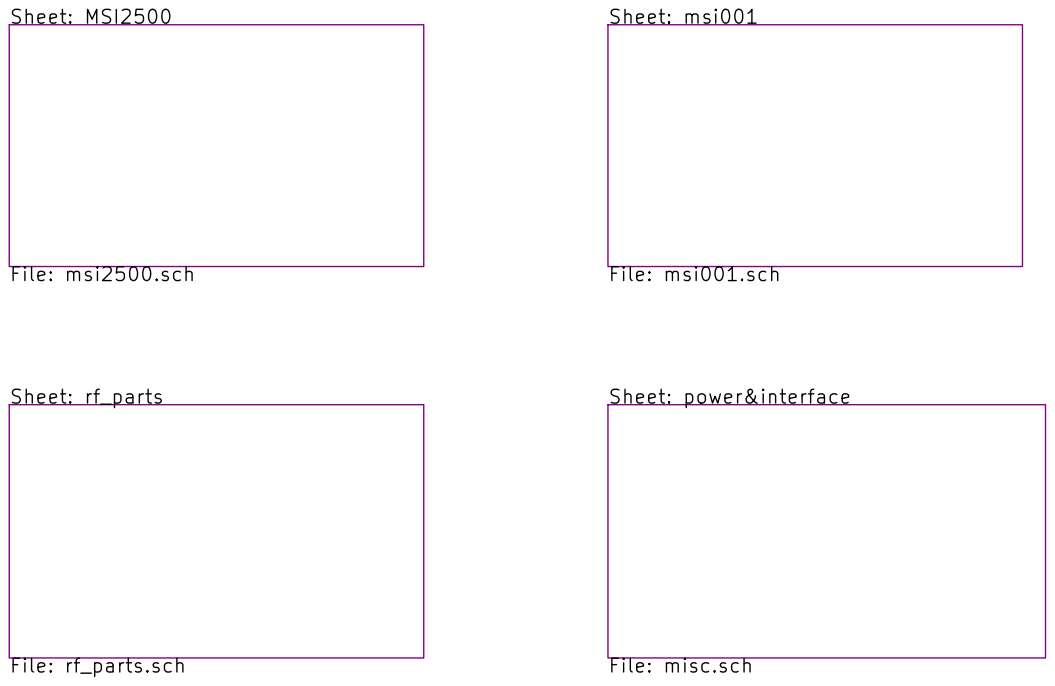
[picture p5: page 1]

Sheet: power&interface File: misc.sch

File: msisdr.sch Sheet: / GigaTechnology / AMSATSA

Id: 1/5 Title: AfriCUBE Satellite

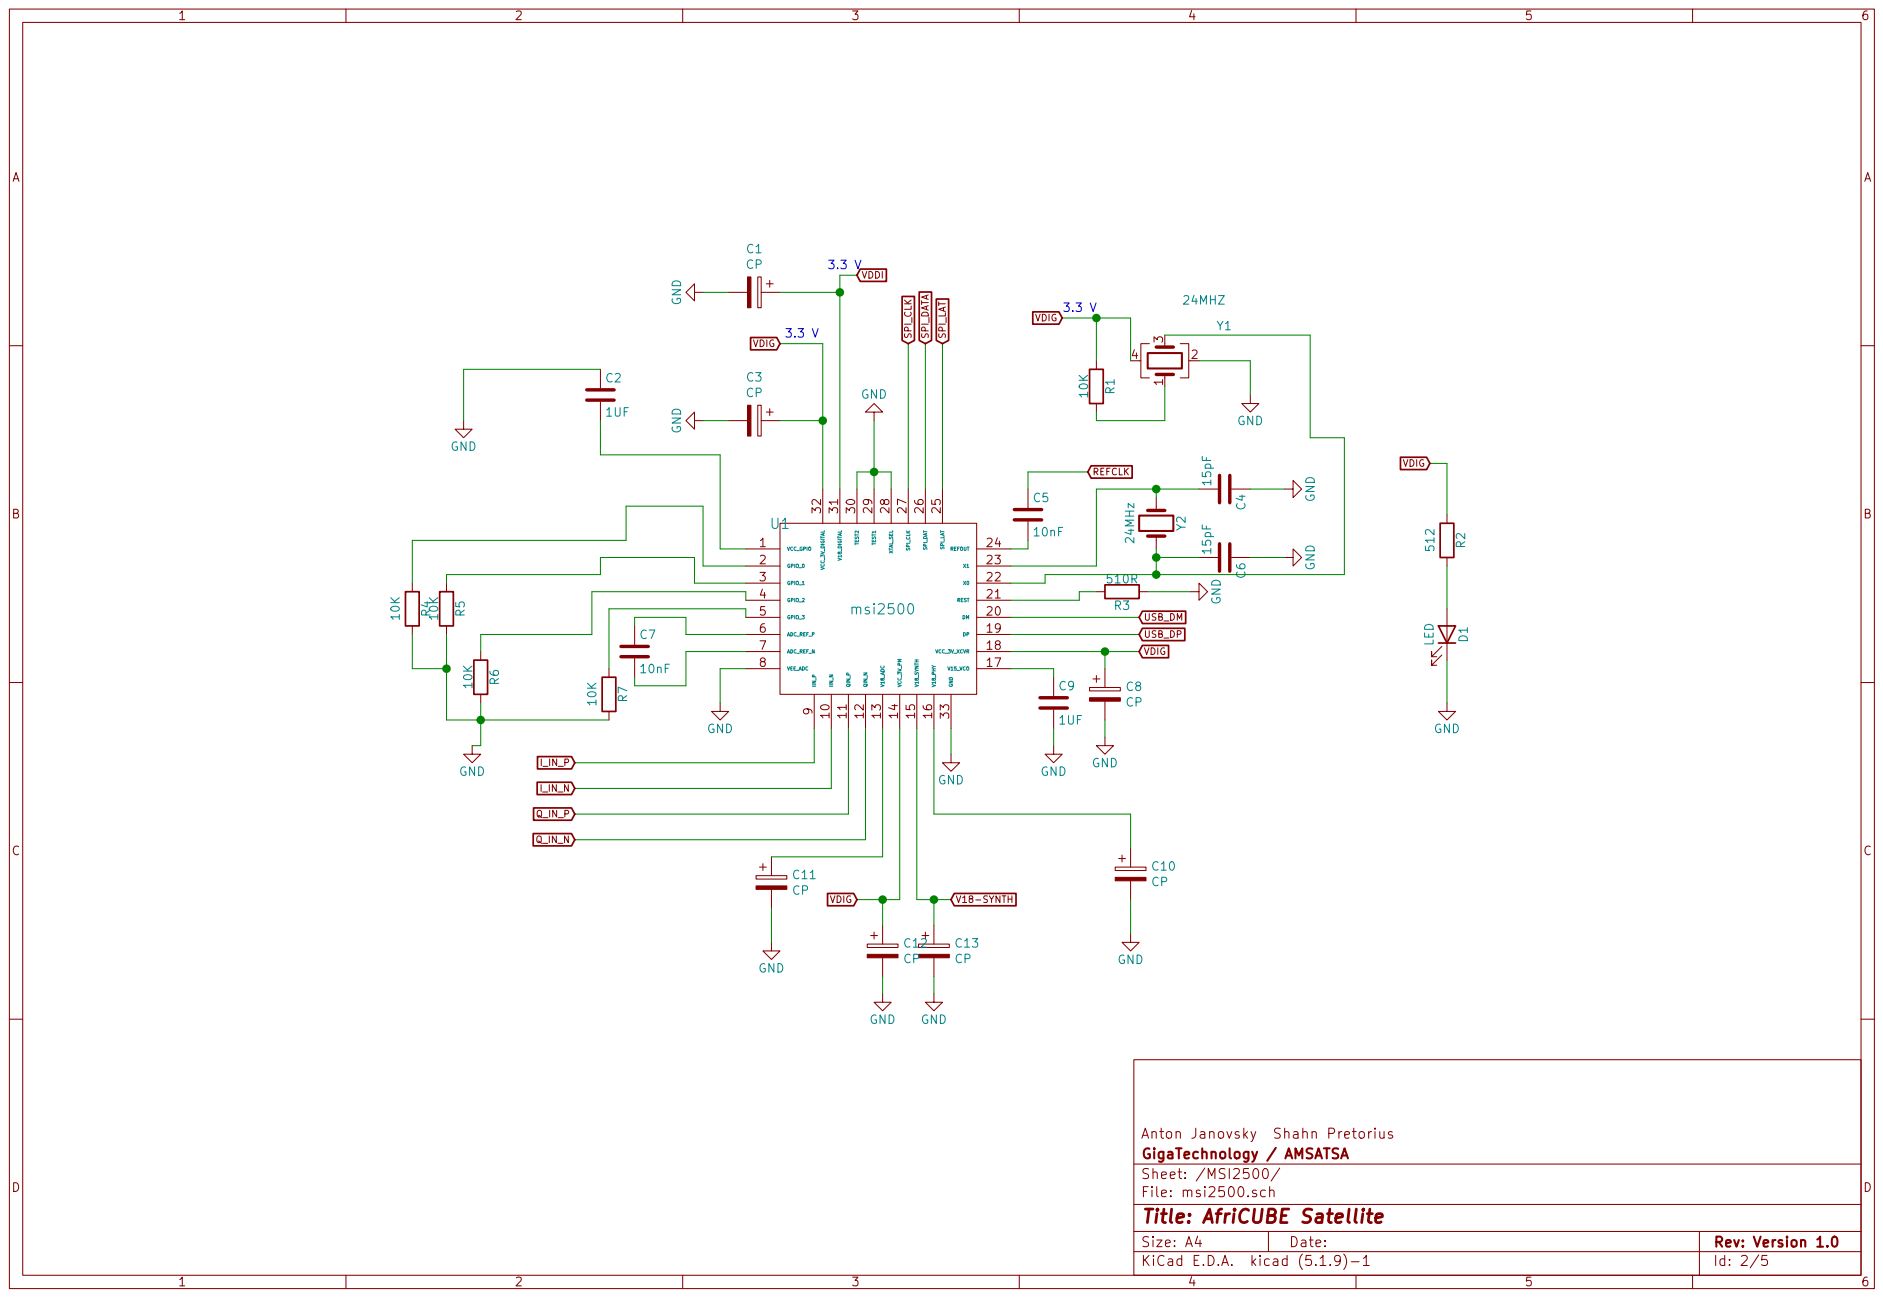
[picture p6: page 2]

File: msi2500.sch Sheet: /MSI2500/ GigaTechnology / AMSATSA

Id: 2/5 Title: AfriCUBE Satellite

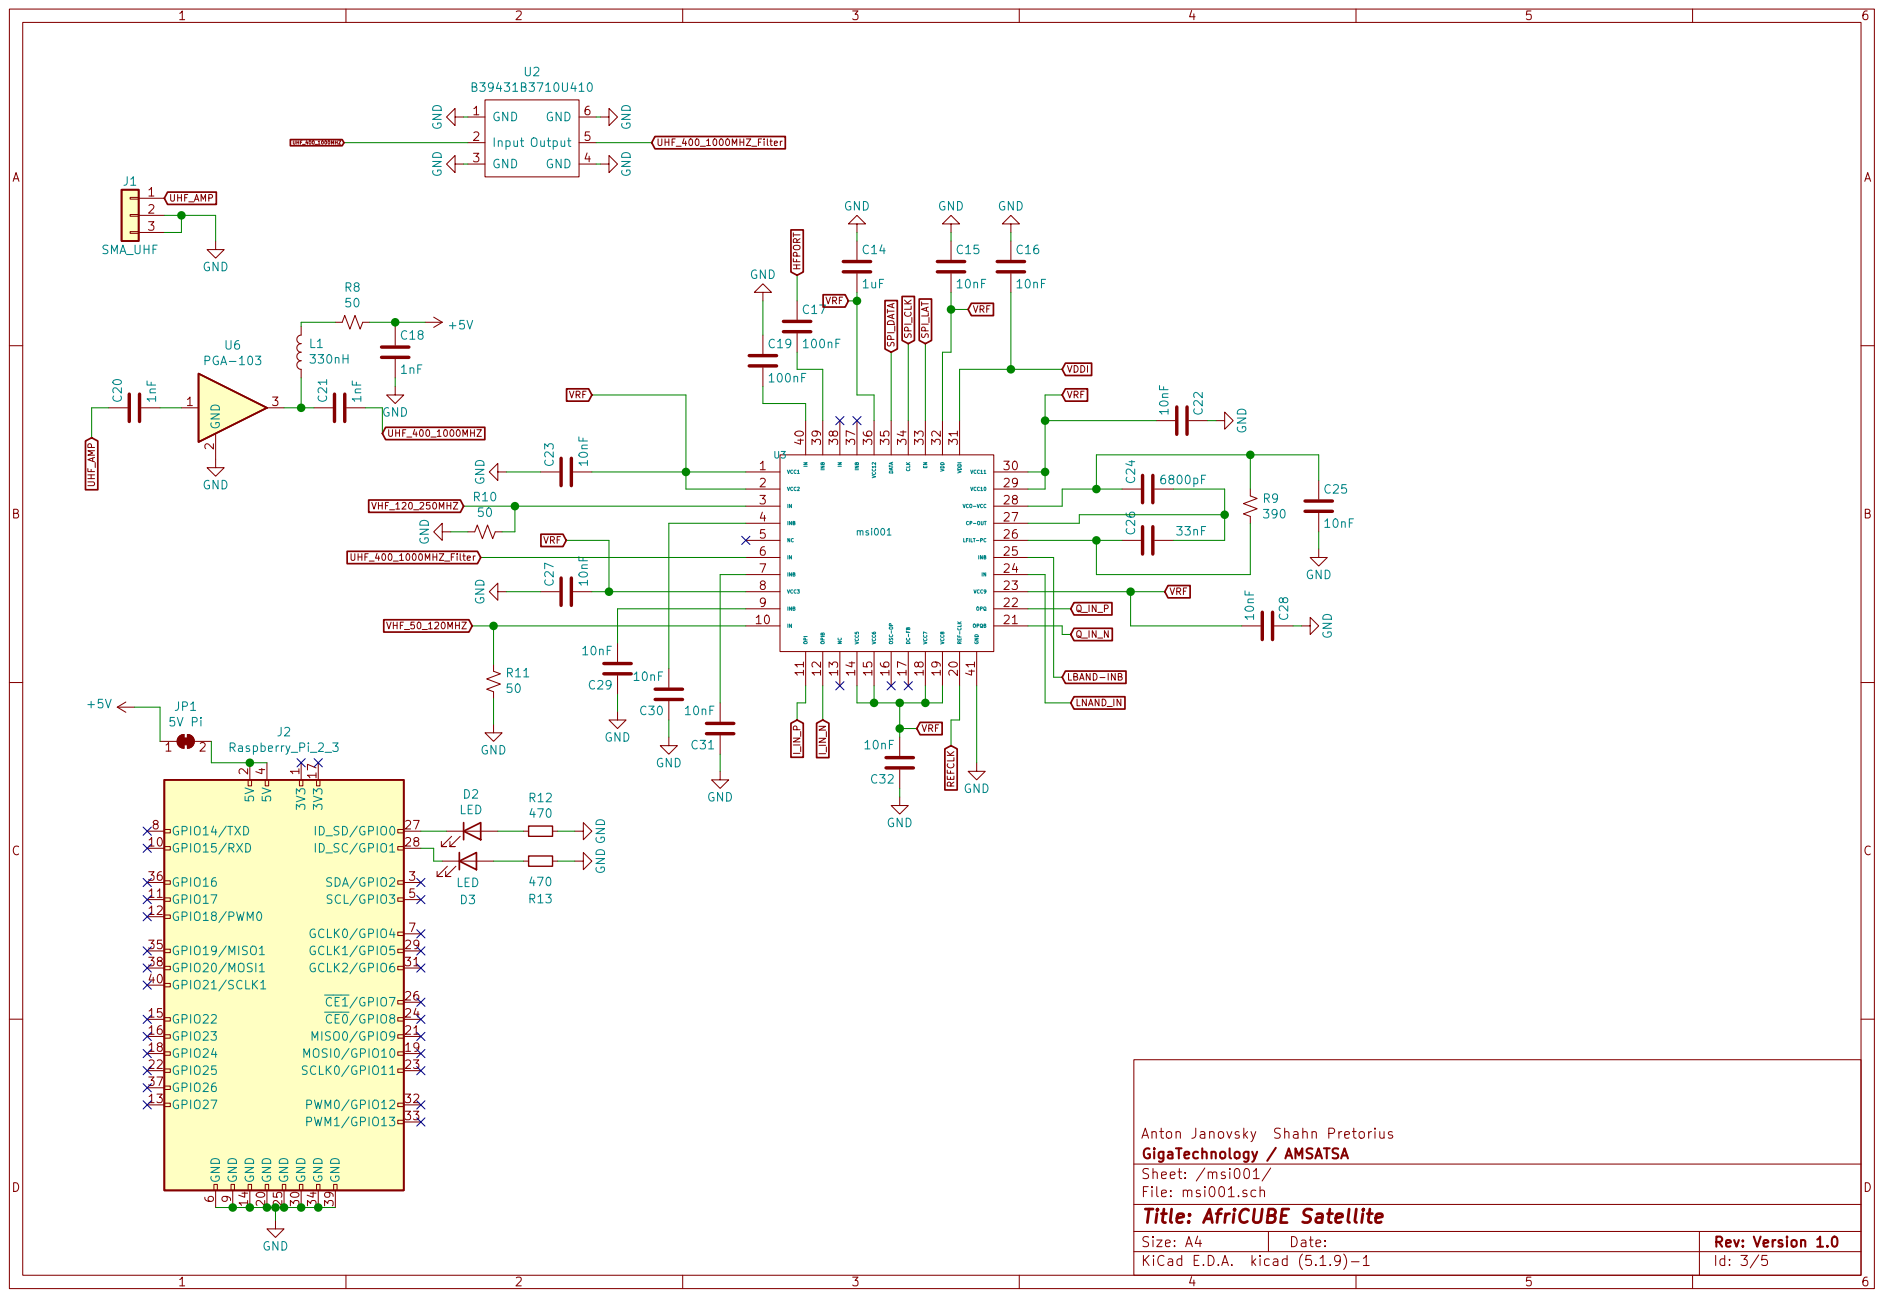
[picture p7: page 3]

File: msi001.sch Sheet: /msi001/ GigaTechnology / AMSATSA

Id: 3/5 Title: AfriCUBE Satellite

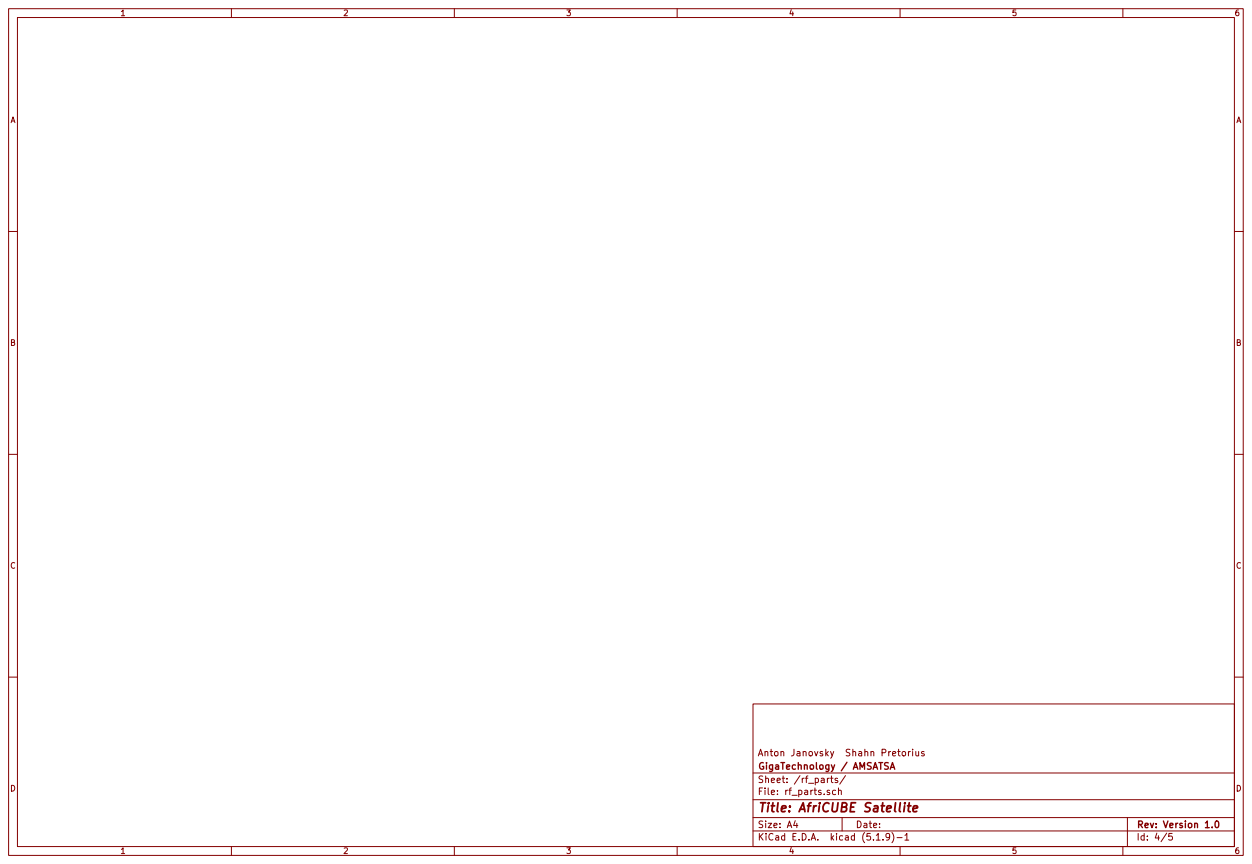
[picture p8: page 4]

GigaTechnology / AMSATSA
Sheet: /rf_parts/
File: rf_parts.sch
Id: 4/5 Title: AfriCUBE Satellite

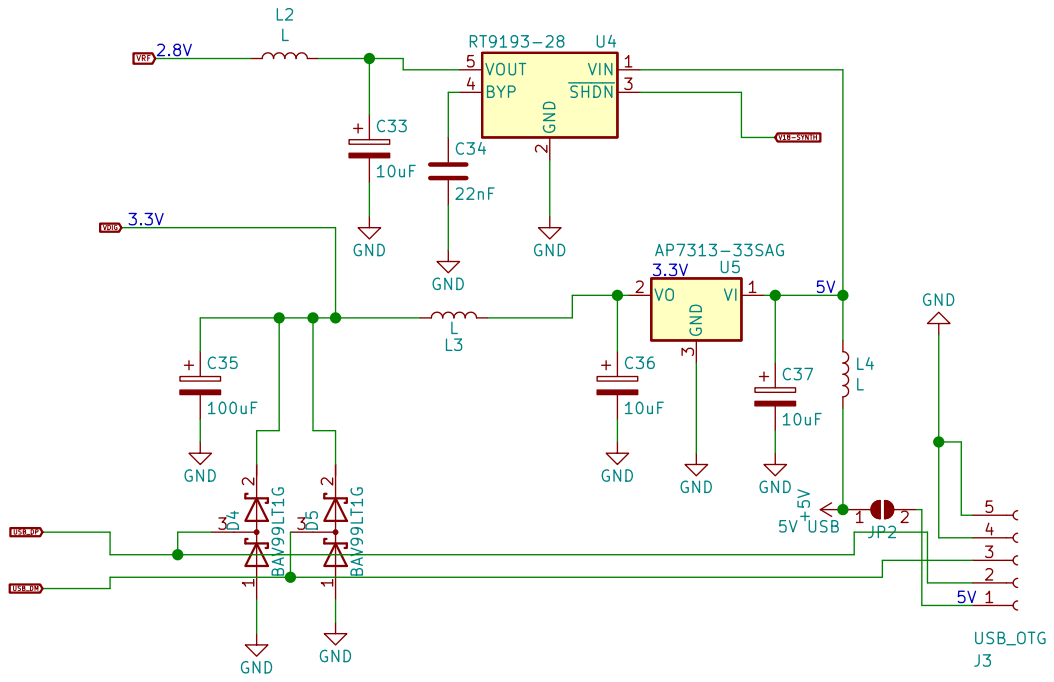
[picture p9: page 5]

2 SHDN 3 BYP 4 VOUT 5 RT9193-28 U4 VI 1 VO 2 GND

GigaTechnology / AMSATSA
File: misc.sch Sheet: /power&interface/
Id: 5/5 Title: AfriCUBE Satellite

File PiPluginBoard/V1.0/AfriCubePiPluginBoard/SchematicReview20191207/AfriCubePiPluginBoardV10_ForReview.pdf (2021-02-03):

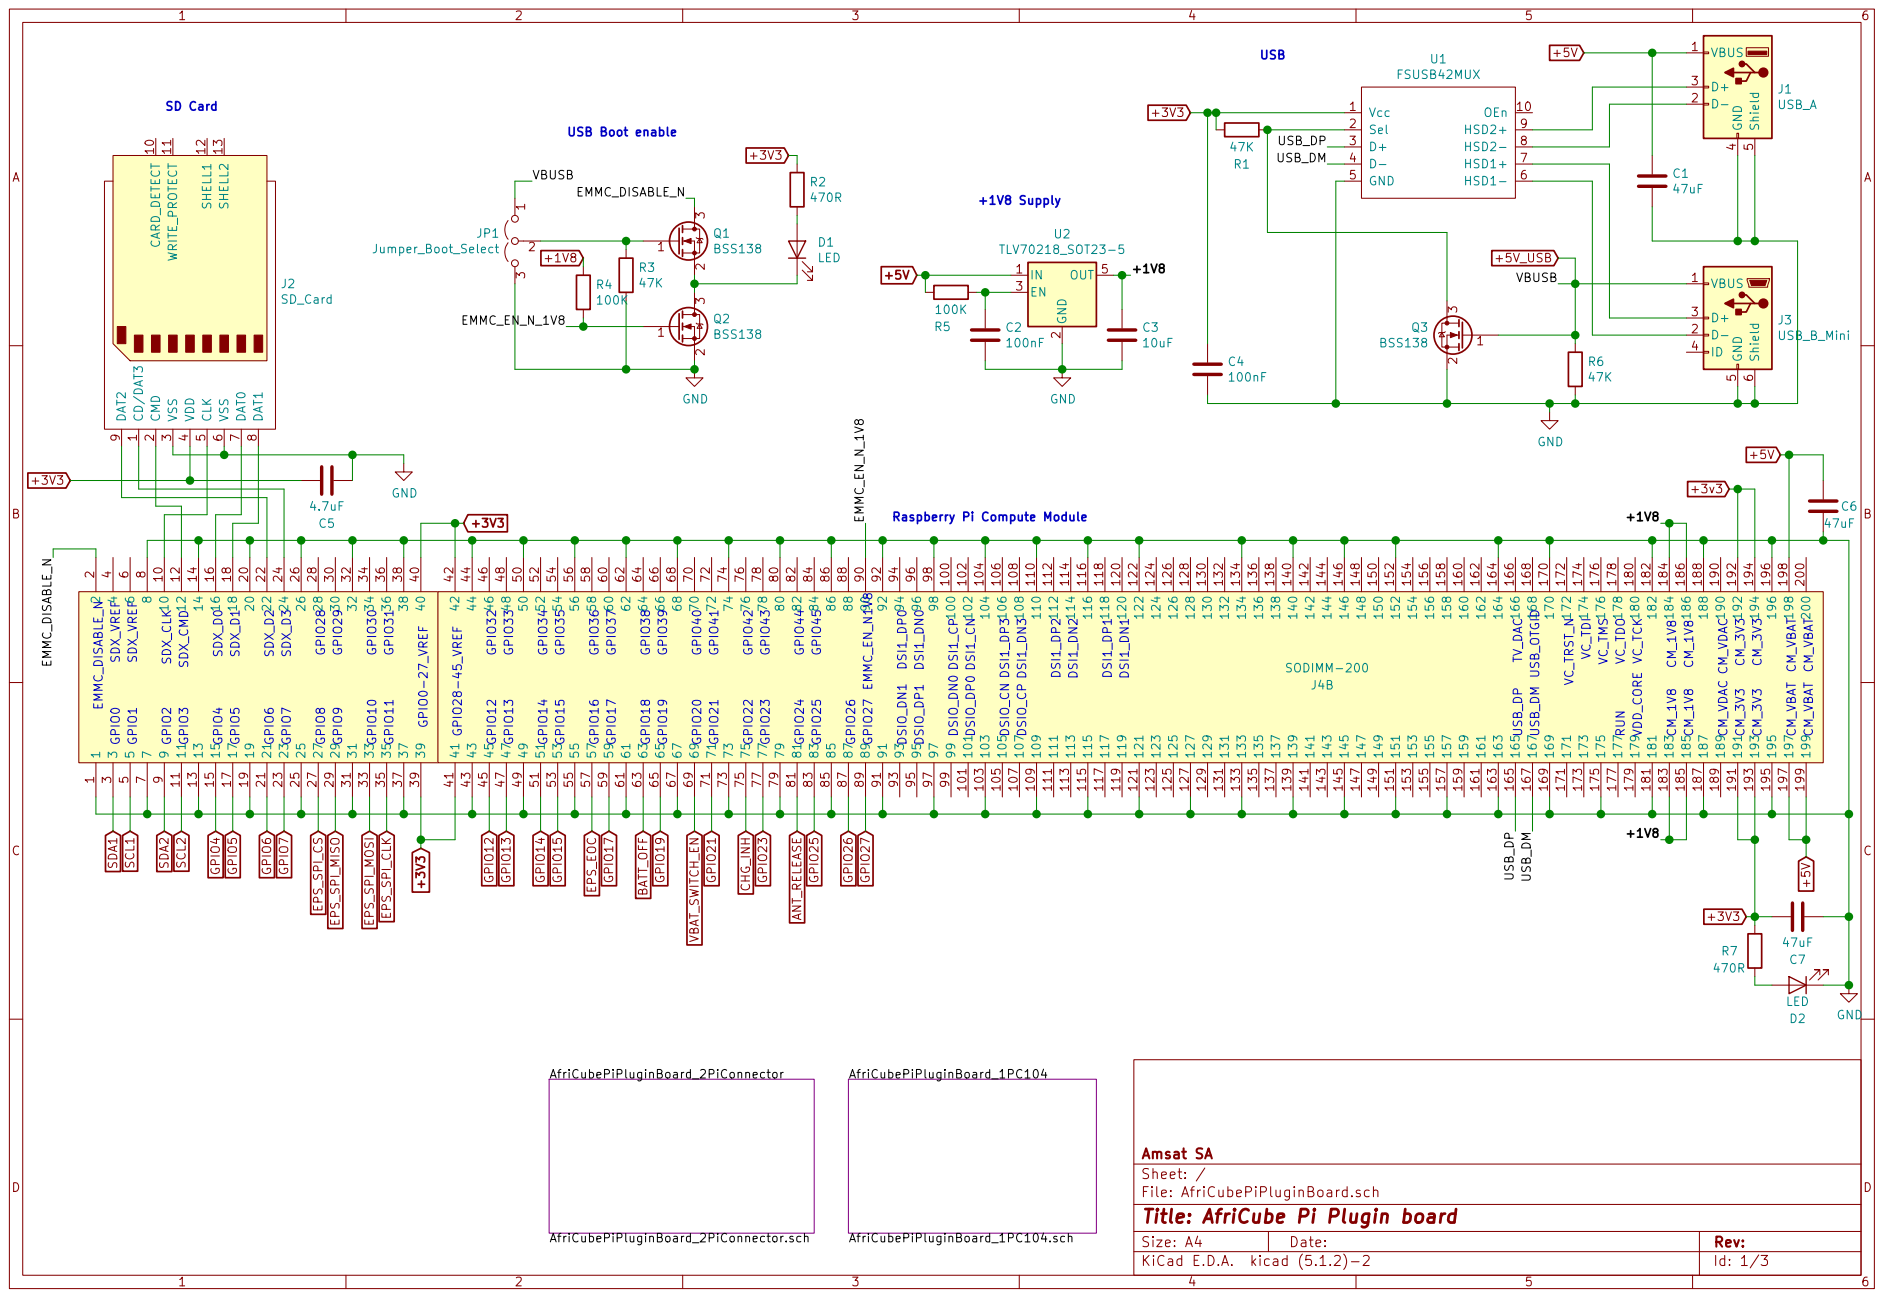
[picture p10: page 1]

EMMC_EN_N_1V8USB Boot enable SD Card

Raspberry Pi Compute Module

File: AfriCubePiPluginBoard.sch Sheet: / Amsat SA

Id: 1/3 Title: AfriCube Pi Plugin board

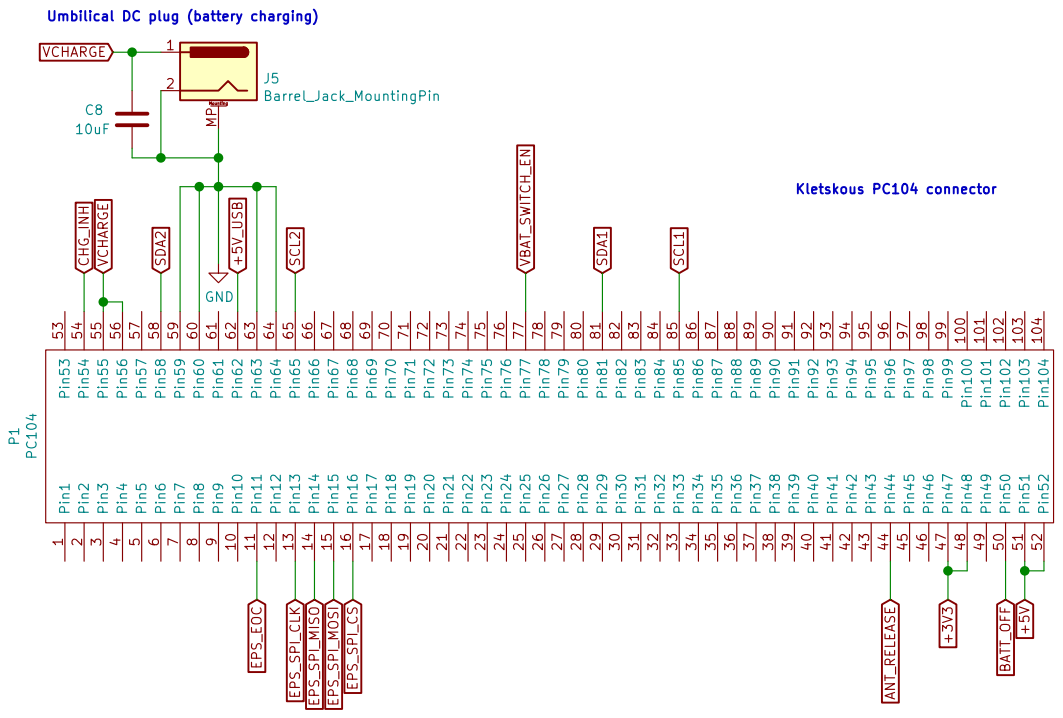
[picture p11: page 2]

File: AfriCubePiPluginBoard_1PC104.sch
Id: 2/3 Title: AfriCube Pi Plugin board

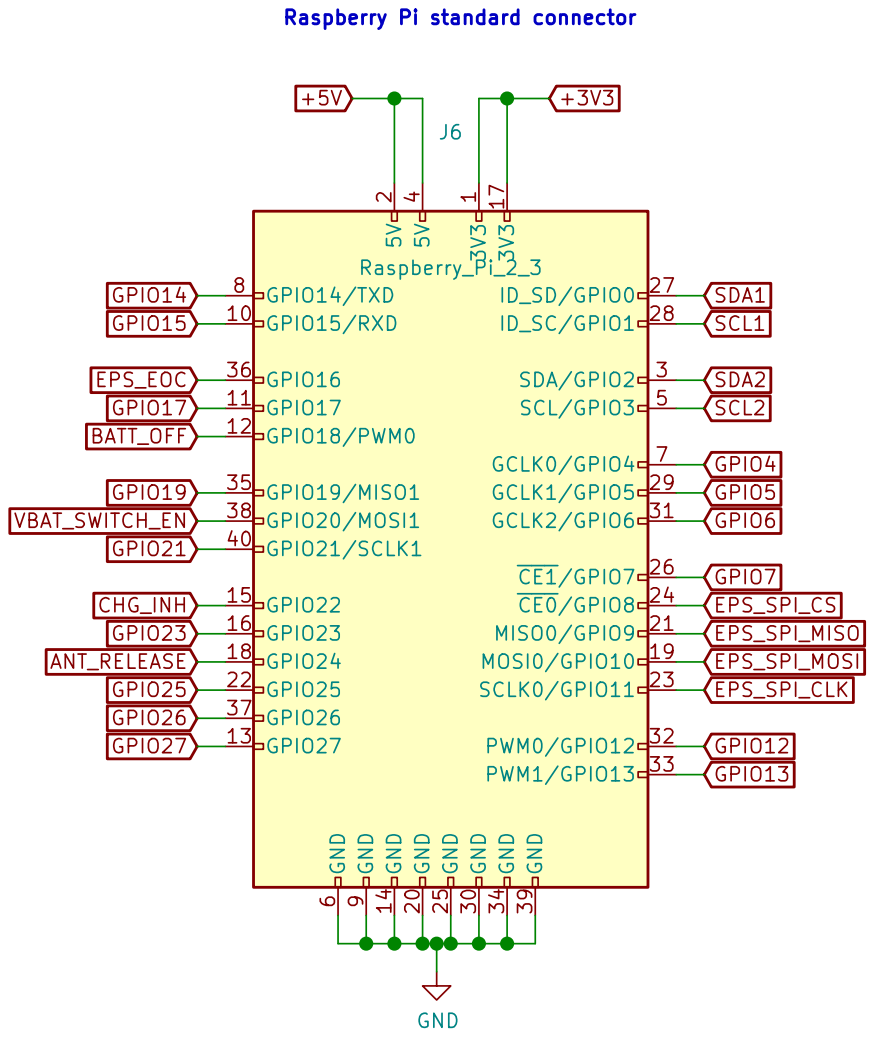
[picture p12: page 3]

File: AfriCubePiPluginBoard_2PiConnector.sch
Id: 3/3 Title: AfriCube Pi Plugin board

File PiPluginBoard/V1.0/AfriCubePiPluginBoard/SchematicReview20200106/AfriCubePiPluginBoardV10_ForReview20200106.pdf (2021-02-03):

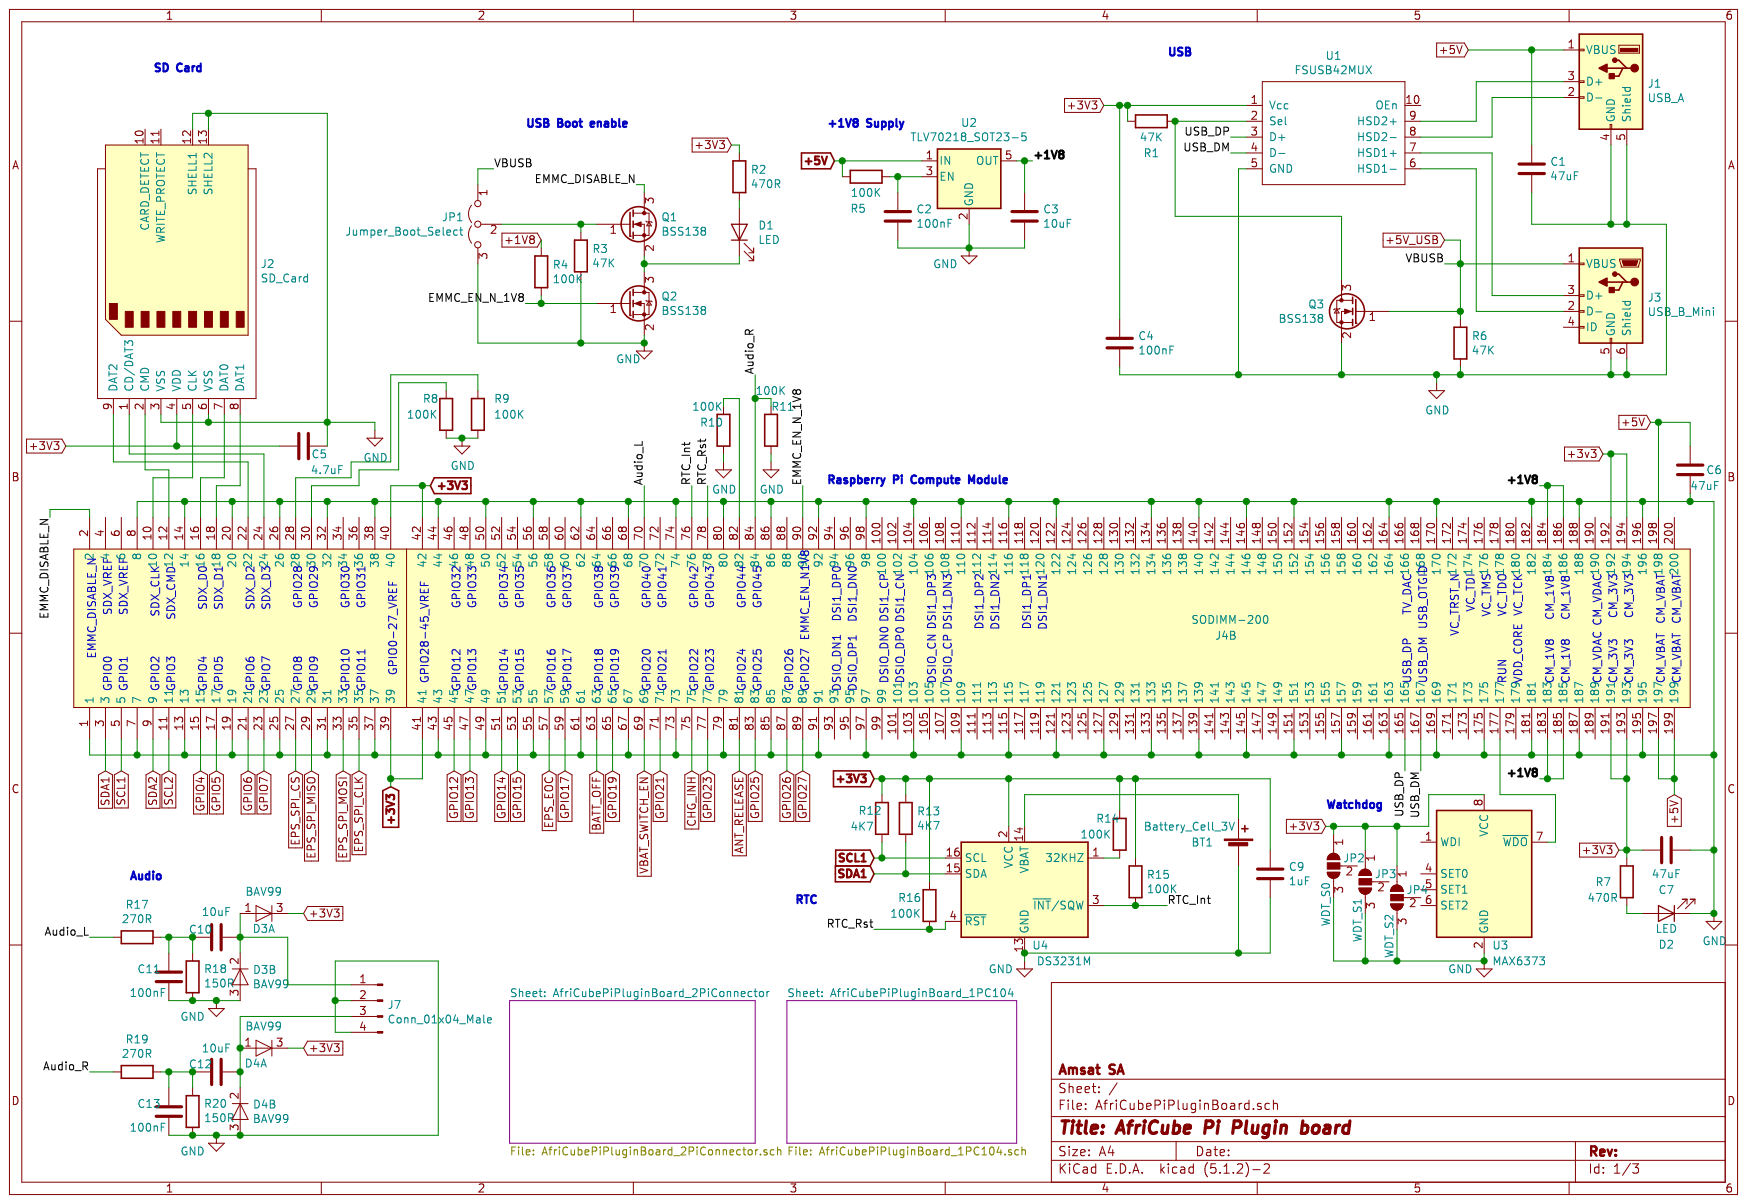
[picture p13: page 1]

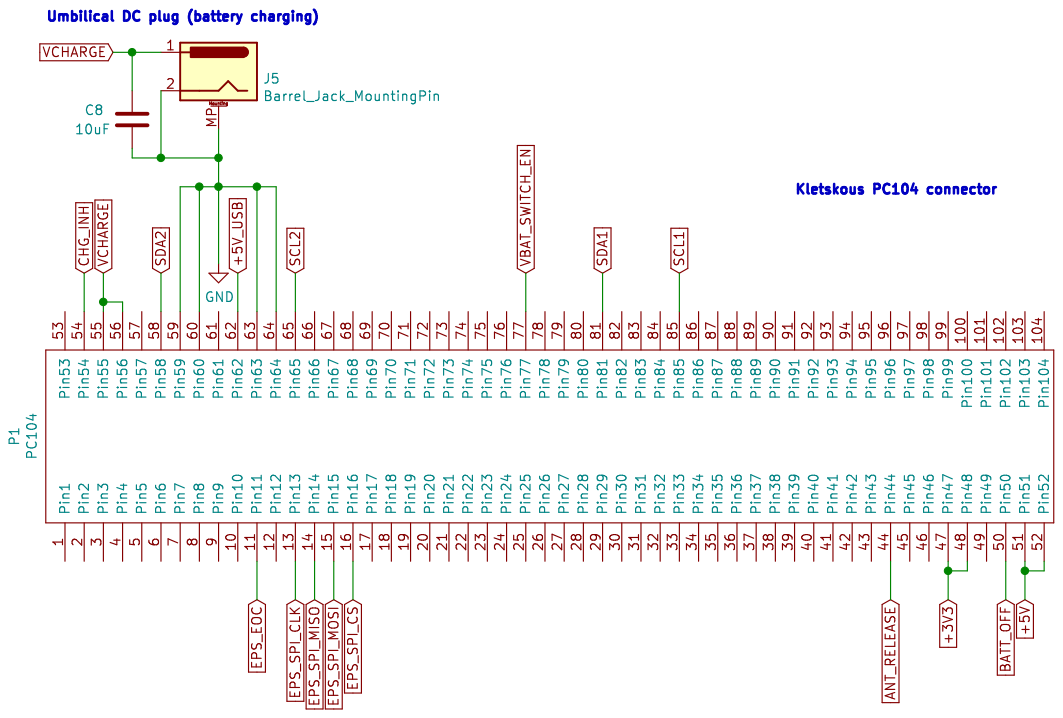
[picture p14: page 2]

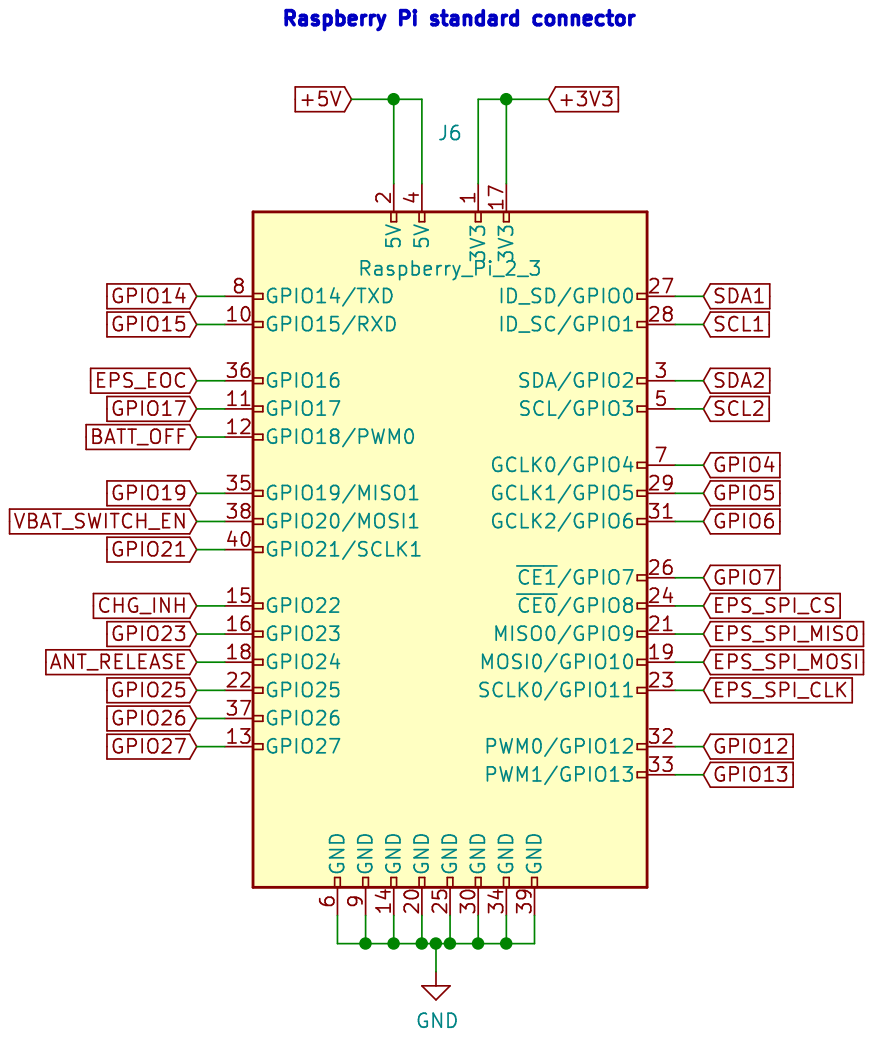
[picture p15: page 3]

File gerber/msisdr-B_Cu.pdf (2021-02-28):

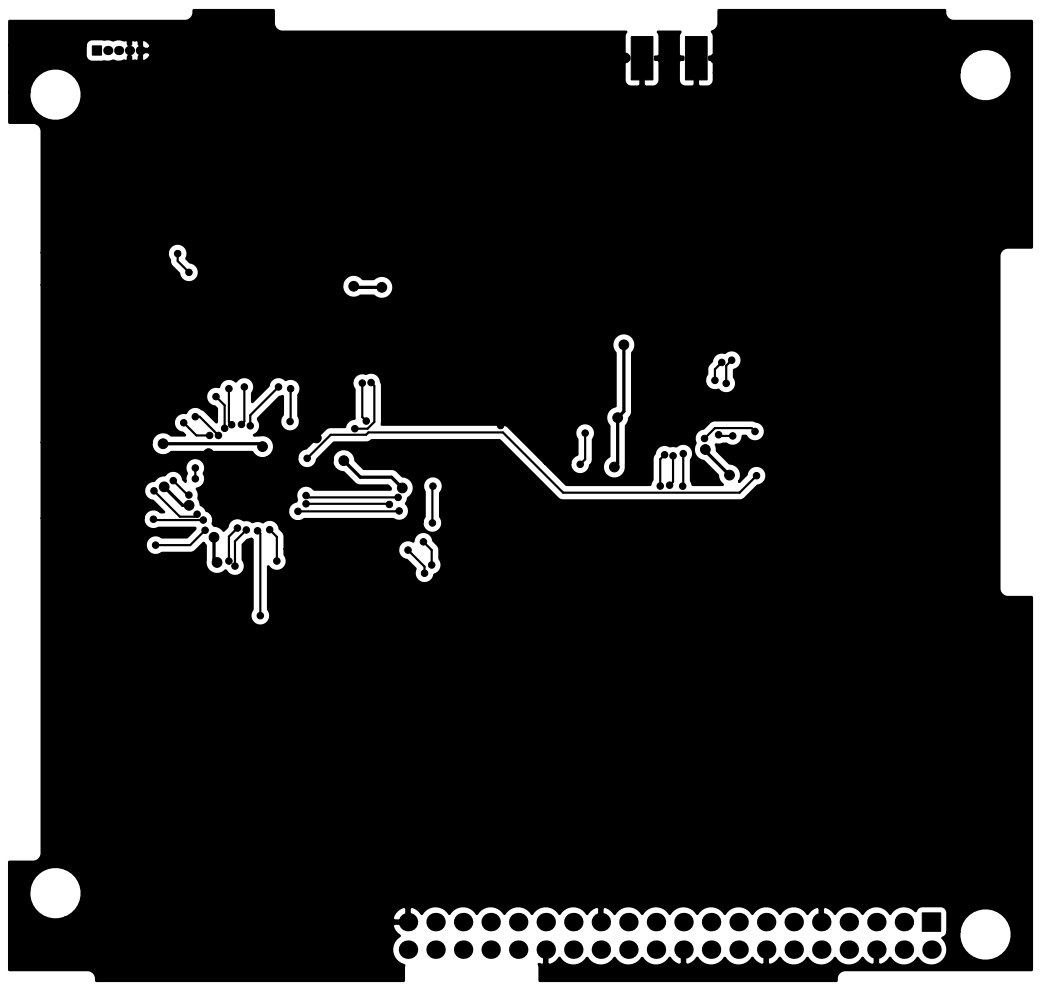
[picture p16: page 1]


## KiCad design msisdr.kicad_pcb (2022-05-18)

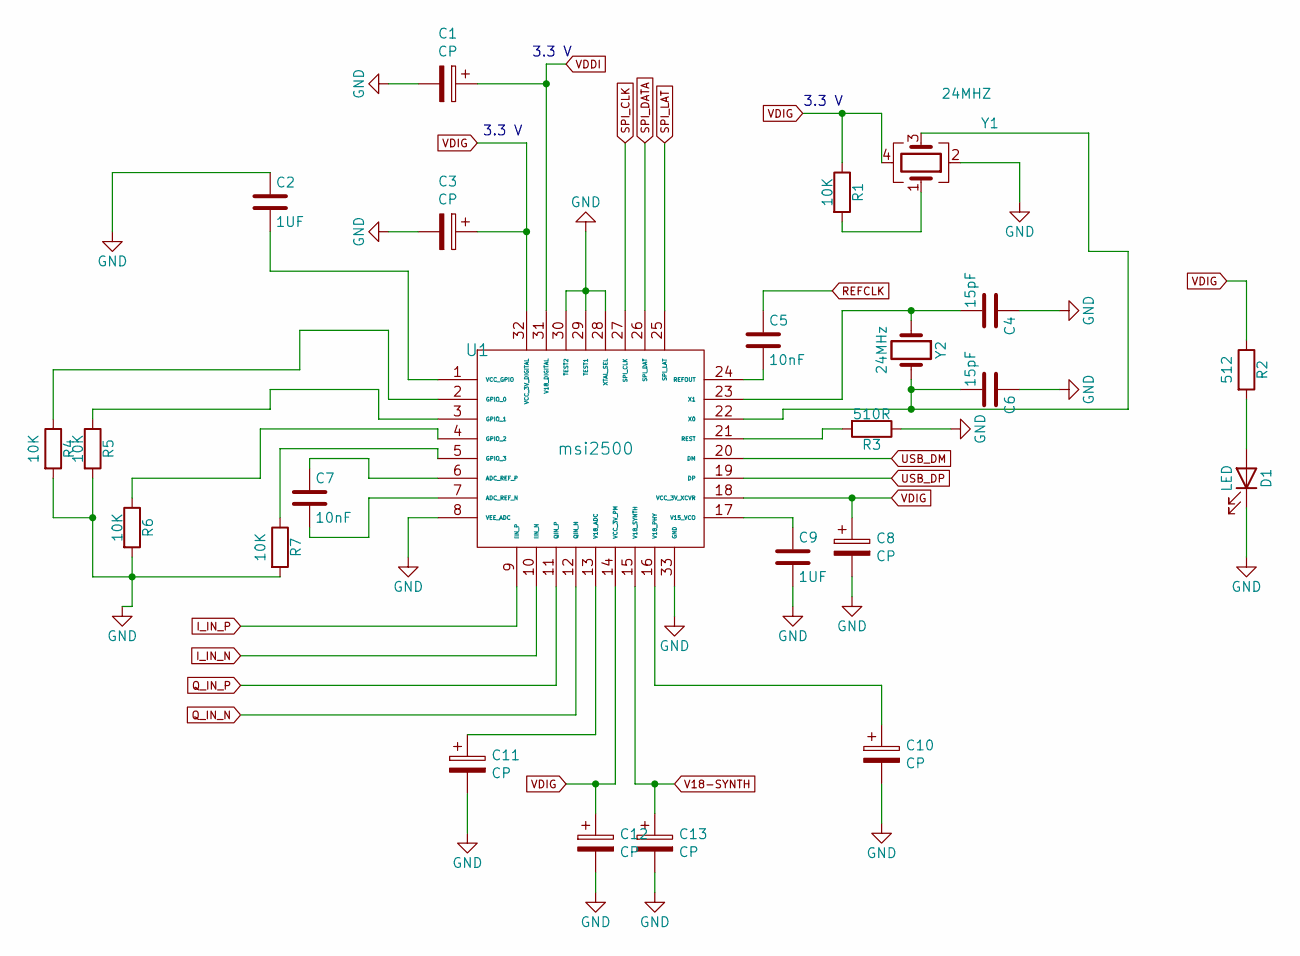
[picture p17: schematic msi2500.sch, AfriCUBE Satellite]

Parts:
C1, C3, C8, C10, C11, C12, C13: CP; CP_EIA-2012-12_Kemet-R
C2, C9: 1UF; C_0805_2012Metric
C4, C6: 15pF; C_0805_2012Metric
C5, C7: 10nF; C_0805_2012Metric
D1: LED; LED_0805_2012Metric
R1, R4, R5, R6, R7: 10K; R_0805_2012Metric
R2: 512; R_0805_2012Metric
R3: 510R; R_0805_2012Metric
U1: msi2500; QFN-32-1EP_5x5mm_P0.5mm_EP3.1x3.1mm
Y1: 24MHZ; Crystal_SMD_7050-4Pin_7.0x5.0mm
Y2: 24MHz; Crystal_SMD_HC49-SD

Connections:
GND: C1.2, C2.1, C3.2, C4.1, C6.1, C8.2, C9.2, C10.2, C11.2, C12.2, C13.2, D1.1 (K), R3.1, R4.2, R5.2, R6.2, R7.2, U1.8 (VEE_ADC), U1.28 (XTAL_SEL), U1.29 (TEST1), U1.30 (TEST2), U1.33 (GND), Y1.2; also elsewhere on the board
I_IN_N: U1.10 (IIN_N); also elsewhere on the board
I_IN_P: U1.9 (IIN_P); also elsewhere on the board
unnamed: C2.2, U1.1 (VCC_GPIO)
unnamed: C4.2, U1.23 (X1), Y2.1
unnamed: C5.2, U1.24 (REFOUT)
unnamed: C6.2, U1.22 (X0), Y1.3, Y2.2
unnamed: C7.1, U1.6 (ADC_REF_P)
unnamed: C7.2, U1.7 (ADC_REF_N)
unnamed: C9.1, U1.17 (V15_VCO)
unnamed: C10.1, U1.16 (V18_PHY)
unnamed: C11.1, U1.13 (V18_ADC)
unnamed: D1.2 (A), R2.2
unnamed: R1.2, Y1.1
unnamed: R3.2, U1.21 (REST)
unnamed: R4.1, U1.2 (GPIO_0)
unnamed: R5.1, U1.3 (GPIO_1)
unnamed: R6.1, U1.4 (GPIO_2)
unnamed: R7.1, U1.5 (GPIO_3)
Q_IN_N: U1.12 (QIN_N); also elsewhere on the board
Q_IN_P: U1.11 (QIN_P); also elsewhere on the board
REFCLK: C5.1; also elsewhere on the board
SPI_CLK: U1.27 (SPI_CLK); also elsewhere on the board
SPI_DATA: U1.26 (SPI_DAT); also elsewhere on the board
SPI_LAT: U1.25 (SPI_LAT); also elsewhere on the board
USB_DM: U1.20 (DM); also elsewhere on the board
USB_DP: U1.19 (DP); also elsewhere on the board
V18-SYNTH: C13.1, U1.15 (V18_SYNTH); also elsewhere on the board
VDDI: C1.1, U1.31 (V18_DIGITAL); also elsewhere on the board
VDIG: C3.1, C8.1, C12.1, R1.1, R2.1, U1.14 (VCC_3V_PM), U1.18 (VCC_3V_XCVR), U1.32 (VCC_3V_DIGITAL), Y1.4; also elsewhere on the board

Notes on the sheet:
3.3 V

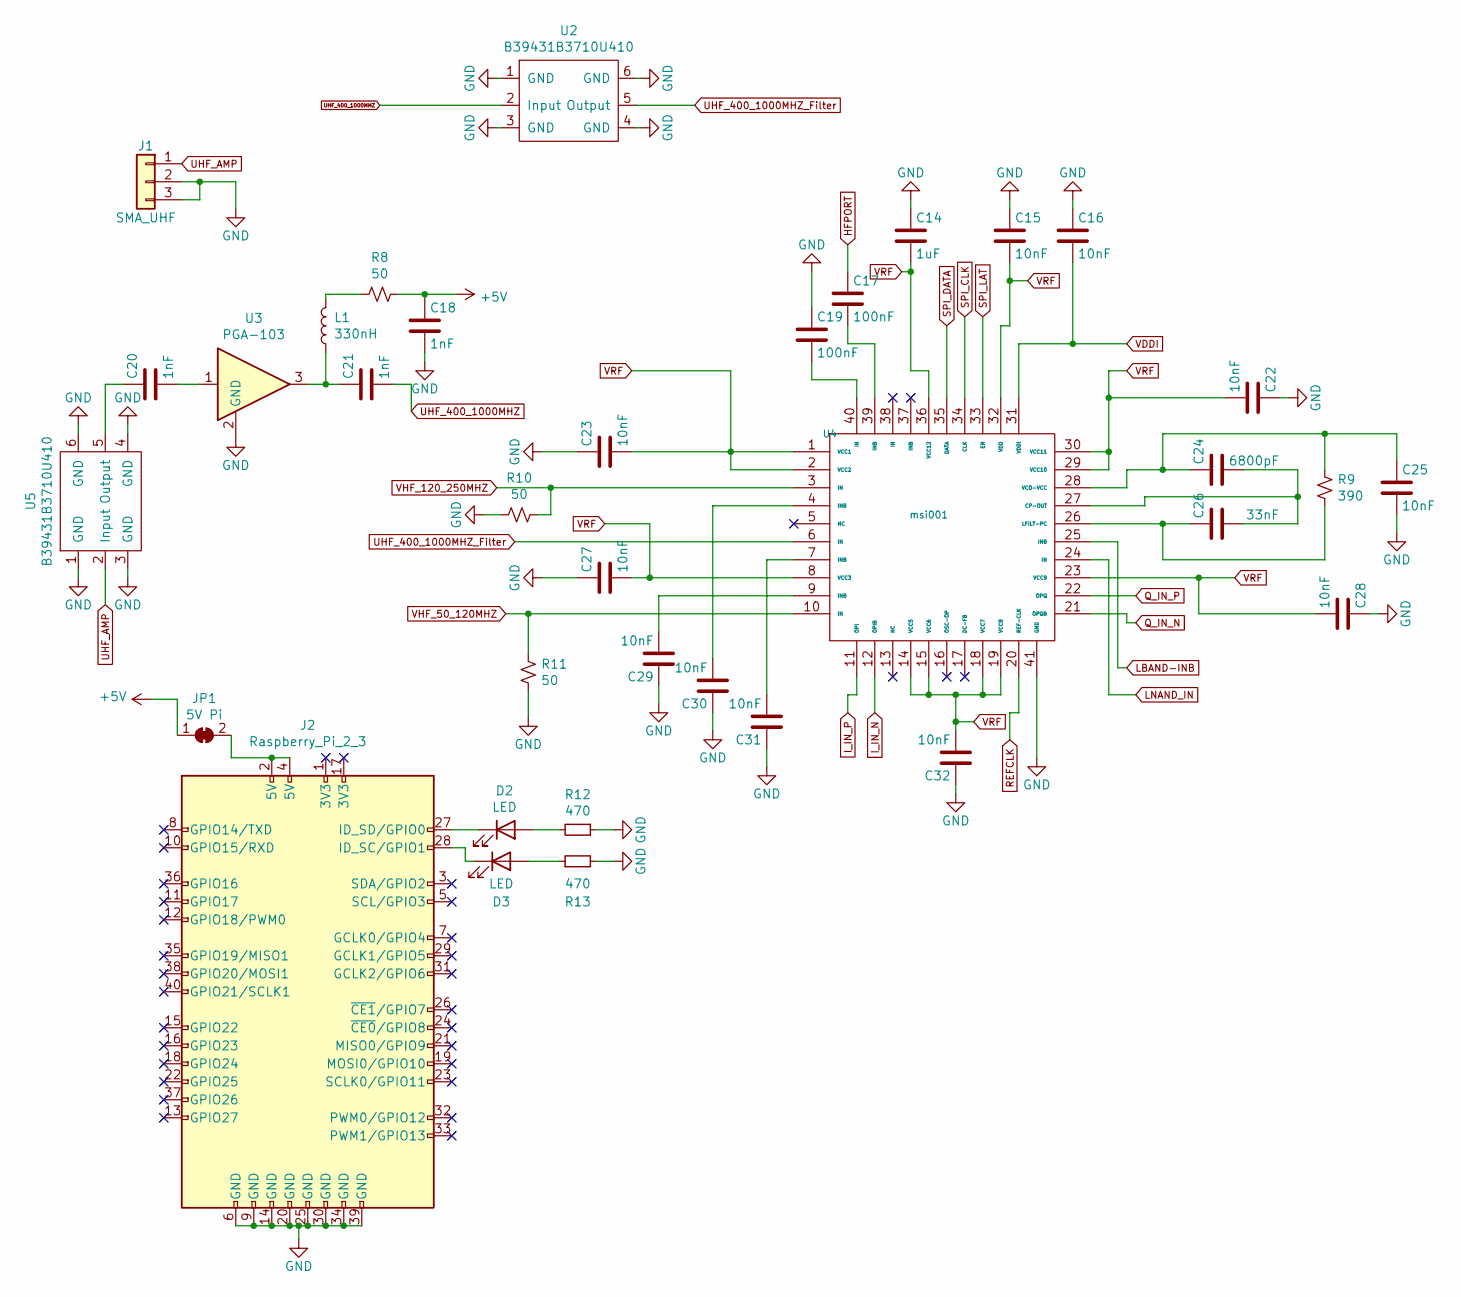
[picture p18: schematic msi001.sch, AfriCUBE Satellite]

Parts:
C14: 1uF; C_0805_2012Metric
C15, C16, C22, C23, C25, C27, C28, C29, C30, C31, C32: 10nF; C_0805_2012Metric
C17, C19: 100nF; C_0805_2012Metric
C18, C20, C21: 1nF; C_0805_2012Metric
C24: 6800pF; C_0805_2012Metric
C26: 33nF; C_0805_2012Metric
D2, D3: LED; LED_0805_2012Metric
J1: SMA_UHF; SMA_OPL_EMPTYHEAD
J2: Raspberry_Pi_2_3; PinHeader_2x20_P2.54mm_Vertical
JP1: 5V Pi; SolderJumper-2_P1.3mm_Bridged_RoundedPad1.0x1.5mm
L1: 330nH; L_0805_2012Metric
R8, R10, R11: 50; R_0805_2012Metric
R9: 390; R_0805_2012Metric
R12, R13: 470; R_0805_2012Metric
U2, U5: B39431B3710U410; DFN-6-1EP_3x3mm_P1mm_EP1.5x2.4mm
U3: PGA-103; SOT-89-3
U4: msi001; QFN-40-1EP_6x6mm_P0.5mm_EP4.6x4.6mm

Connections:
+5V: C18.1, JP1.1 (A), R8.1; also elsewhere on the board
GND: C14.1, C15.1, C16.1, C18.2, C19.1, C22.1, C23.1, C25.2, C27.1, C28.1, C29.1, C30.1, C31.1, C32.1, J1.2, J1.3, J2.6 (GND), J2.9 (GND), J2.14 (GND), J2.20 (GND), J2.25 (GND), J2.30 (GND), J2.34 (GND), J2.39 (GND), R10.2, R11.1, R12.1, R13.2, U2.1 (GND), U2.3 (GND), U2.4 (GND), U2.6 (GND), U3.2 (GND), U4.41 (GND), U5.1 (GND), U5.3 (GND), U5.4 (GND), U5.6 (GND); also elsewhere on the board
HFPORT: C17.1
I_IN_N: U4.12 (OPIB); also elsewhere on the board
I_IN_P: U4.11 (OPI); also elsewhere on the board
LBAND-INB: U4.25 (INB)
LNAND_IN: U4.24 (IN)
unnamed: C17.2, U4.39 (INB)
unnamed: C19.2, U4.40 (IN)
unnamed: C20.1, U5.5 (Output)
unnamed: C20.2, U3.1
unnamed: C21.1, L1.1, U3.3
unnamed: C24.1, C25.1, R9.1, U4.28 (VCO-VCC)
unnamed: C24.2, C26.2, U4.27 (CP-OUT)
unnamed: C26.1, R9.2, U4.26 (LFILT-PC)
unnamed: C29.2, U4.9 (INB)
unnamed: C30.2, U4.4 (INB)
unnamed: C31.2, U4.7 (INB)
unnamed: D2.1 (K), J2.27 (ID_SD/GPIO0)
unnamed: D2.2 (A), R12.2
unnamed: D3.1 (K), J2.28 (ID_SC/GPIO1)
unnamed: D3.2 (A), R13.1
unnamed: J2.2 (5V), J2.4 (5V), JP1.2 (B)
unnamed: L1.2, R8.2
Q_IN_N: U4.21 (OPQB); also elsewhere on the board
Q_IN_P: U4.22 (OPQ); also elsewhere on the board
REFCLK: U4.20 (REF-CLK); also elsewhere on the board
SPI_CLK: U4.34 (CLK); also elsewhere on the board
SPI_DATA: U4.35 (DATA); also elsewhere on the board
SPI_LAT: U4.33 (EN); also elsewhere on the board
UHF_400_1000MHZ: C21.2, U2.2 (Input)
UHF_400_1000MHZ_Filter: U2.5 (Output), U4.6 (IN)
UHF_AMP: J1.1, U5.2 (Input)
VDDI: C16.2, U4.31 (VDDI); also elsewhere on the board
VHF_50_120MHZ: R11.2, U4.10 (IN)
VHF_120_250MHZ: R10.1, U4.3 (IN)
VRF: C14.2, C15.2, C22.2, C23.2, C27.2, C28.2, C32.2, U4.1 (VCC1), U4.2 (VCC2), U4.8 (VCC3), U4.14 (VCC5), U4.15 (VCC6), U4.18 (VCC7), U4.19 (VCC8), U4.23 (VCC9), U4.29 (VCC10), U4.30 (VCC11), U4.32 (VDD), U4.36 (VCC12); also elsewhere on the board

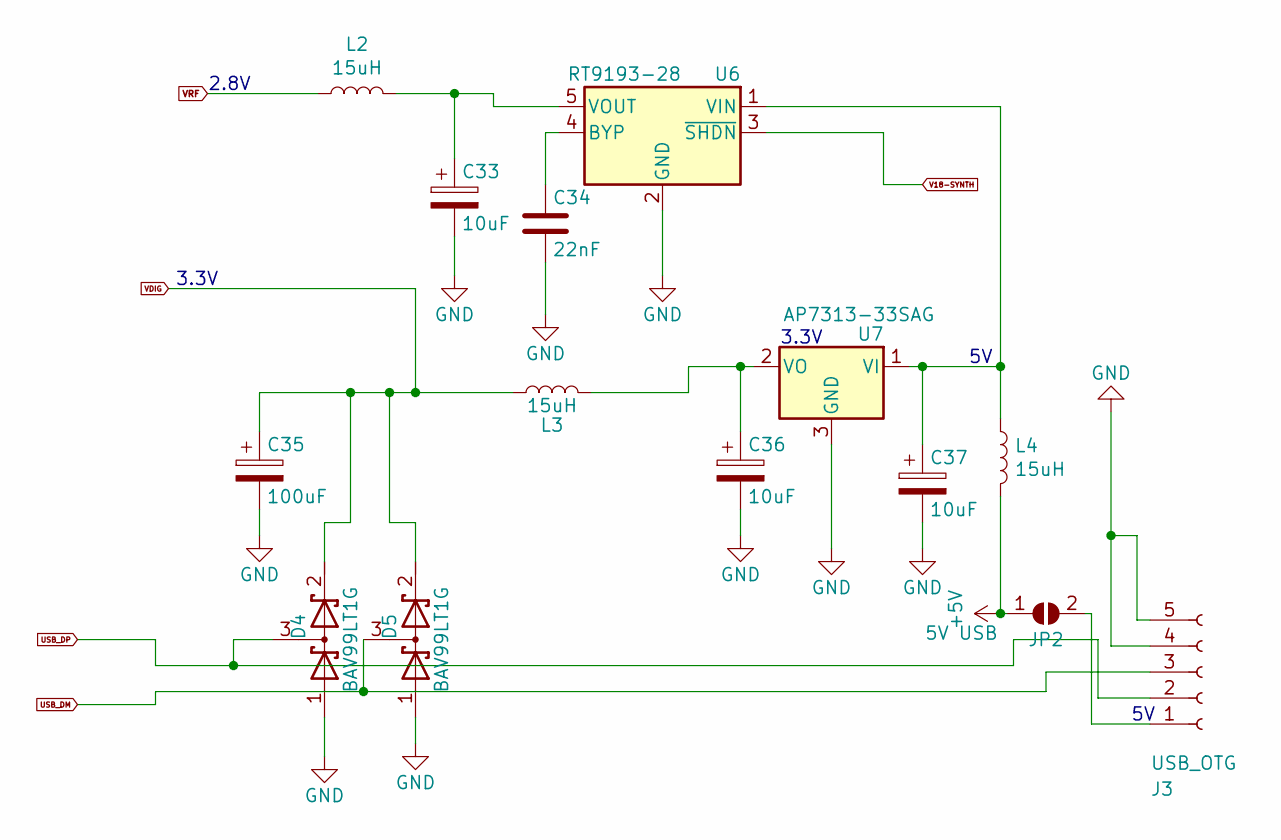
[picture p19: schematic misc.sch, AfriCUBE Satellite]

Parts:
C33, C36, C37: 10uF; CP_EIA-2012-12_Kemet-R
C34: 22nF; C_0805_2012Metric
C35: 100uF; CP_EIA-7343-15_Kemet-W
D4, D5: BAV99LT1G; SOT-23
J3: USB_OTG; PinHeader_1x05_P1.00mm_Vertical
JP2: 5V USB; SolderJumper-2_P1.3mm_Open_RoundedPad1.0x1.5mm
L2, L3, L4: 15uH; L_1210_3225Metric
U6: RT9193-28; SOT-23-5
U7: AP7313-33SAG; SOT-23

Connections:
+5V: JP2.1 (A), L4.2; also elsewhere on the board
GND: C33.2, C34.2, C35.2, C36.2, C37.2, D4.1 (A), D5.1 (A), J3.4, J3.5, U6.2 (GND), U7.3 (GND); also elsewhere on the board
unnamed: C33.1, L2.2, U6.5 (VOUT)
unnamed: C34.1, U6.4 (BYP)
unnamed: C36.1, L3.2, U7.2 (VO)
unnamed: C37.1, L4.1, U6.1 (VIN), U7.1 (VI)
unnamed: J3.1, JP2.2 (B)
USB_DM: D5.3 (common), J3.3; also elsewhere on the board
USB_DP: D4.3 (common), J3.2; also elsewhere on the board
V18-SYNTH: U6.3 (~SHDN~); also elsewhere on the board
VDIG: C35.1, D4.2 (K), D5.2 (K), L3.1; also elsewhere on the board
VRF: L2.1; also elsewhere on the board

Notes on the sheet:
3.3V
2.8V

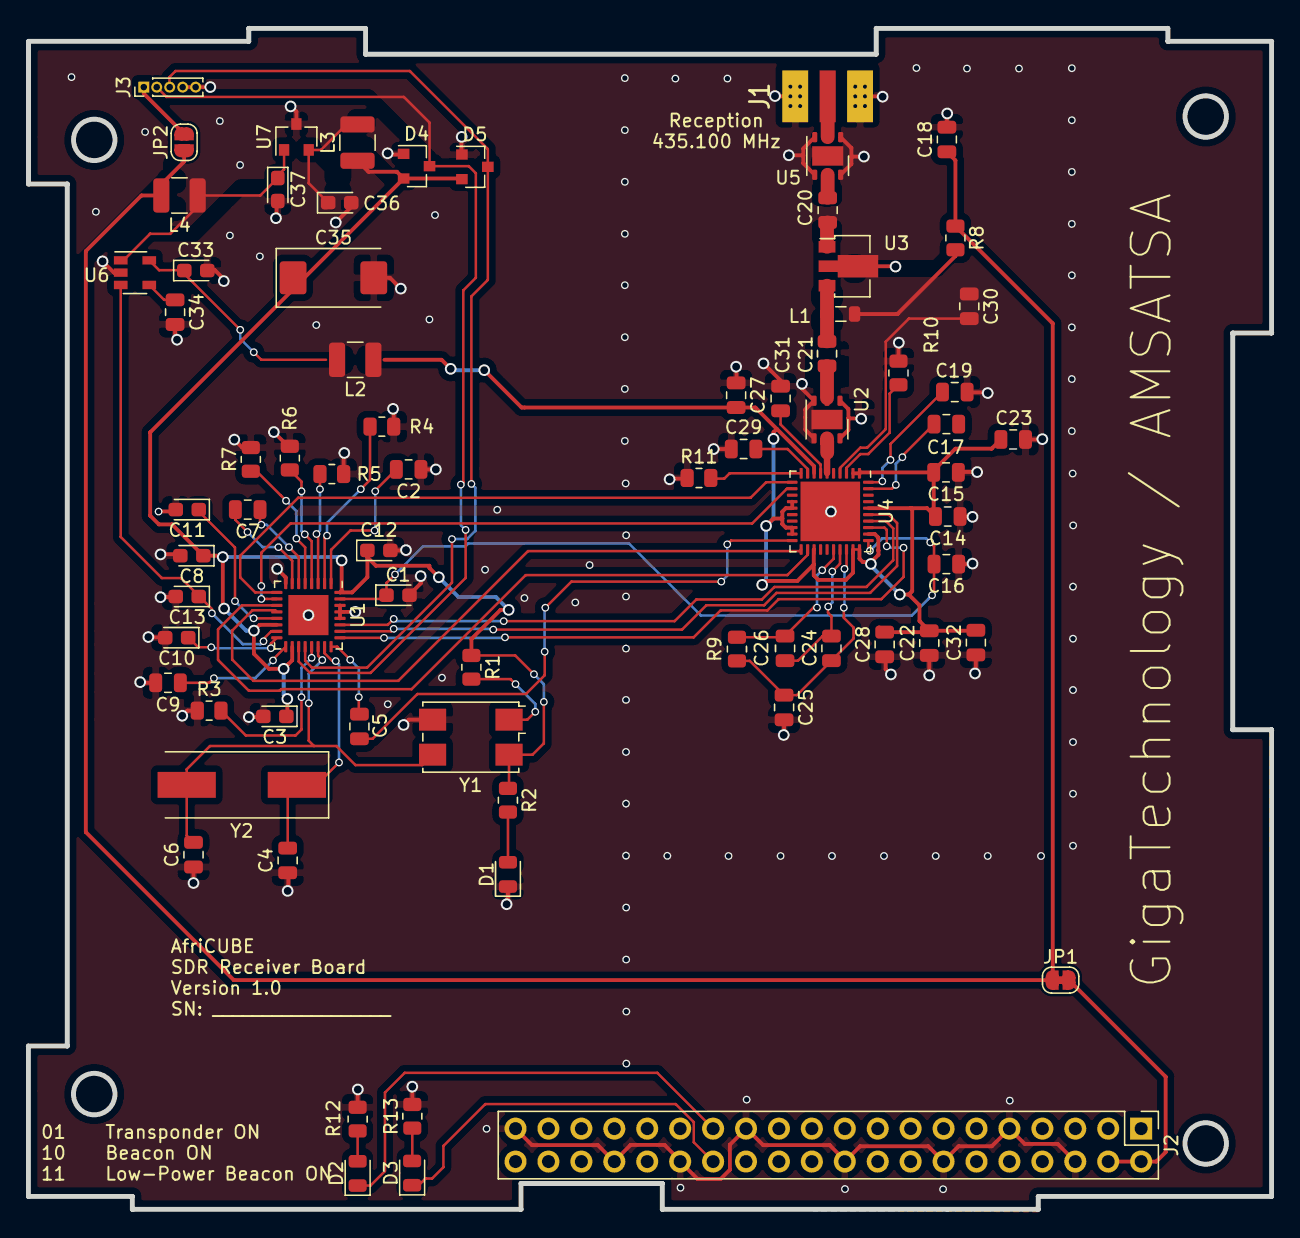
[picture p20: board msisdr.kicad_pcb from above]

Board: 2 copper layers, 95.9 x 91.1 mm, 73 parts (0 on the bottom side), 59 nets.

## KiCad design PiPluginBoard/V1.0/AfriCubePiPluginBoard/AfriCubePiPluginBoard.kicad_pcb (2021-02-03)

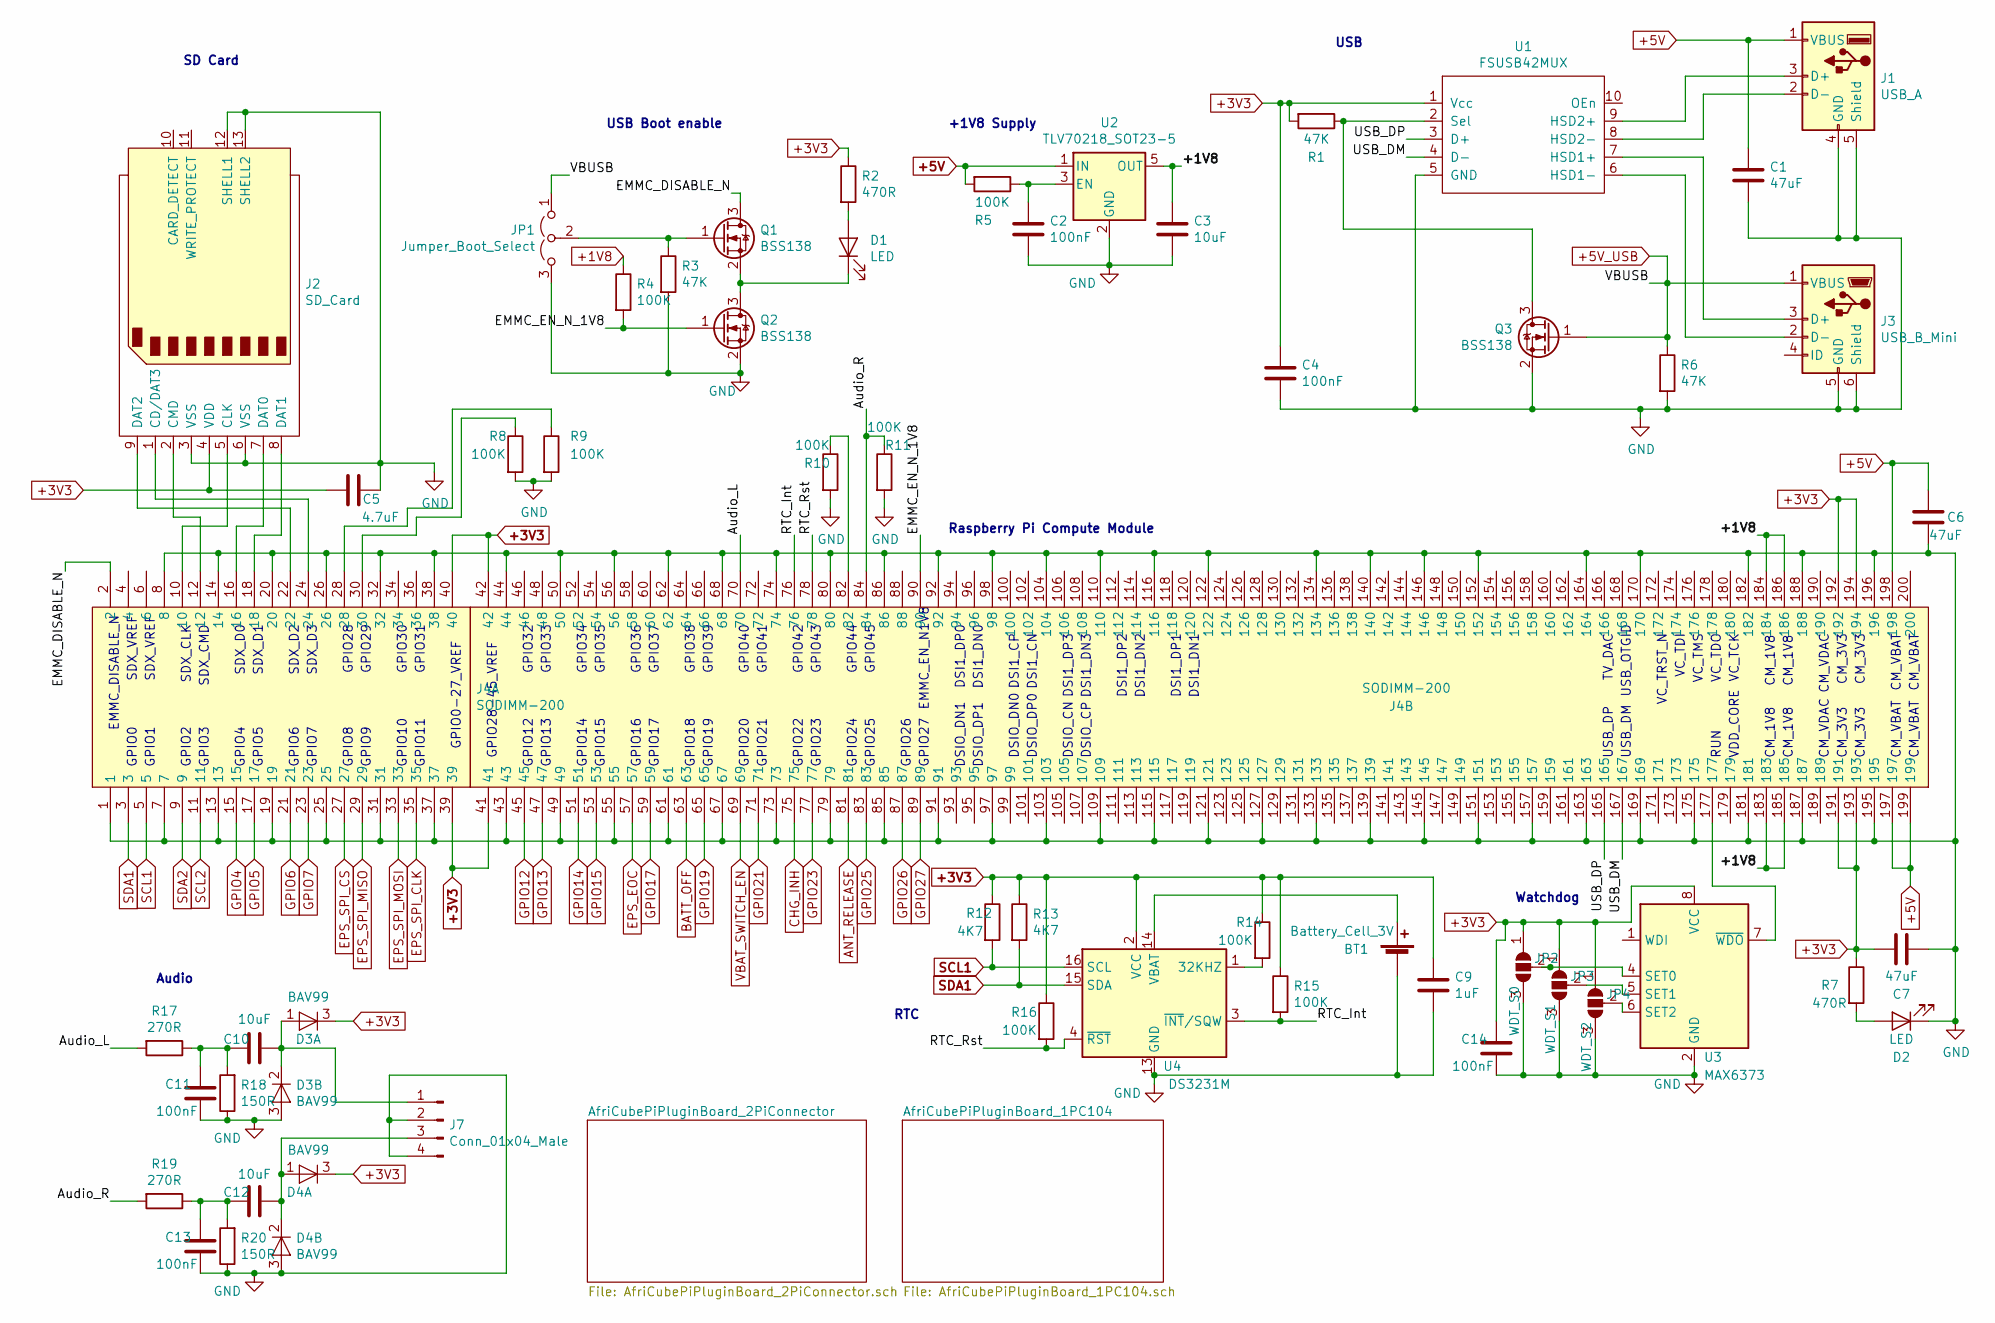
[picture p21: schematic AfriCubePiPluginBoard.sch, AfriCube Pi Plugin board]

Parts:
BT1: Battery_Cell_3V; BatteryHolder_Keystone_3000_1x12mm
C1, C6, C7: 47uF; R_1210_3225Metric_Pad1.42x2.65mm_HandSolder
C2, C4, C11, C13, C14: 100nF; R_0805_2012Metric_Pad1.15x1.40mm_HandSolder
C3, C10, C12: 10uF; R_0805_2012Metric_Pad1.15x1.40mm_HandSolder
C5: 4.7uF; R_0805_2012Metric_Pad1.15x1.40mm_HandSolder
C9: 1uF; R_0805_2012Metric_Pad1.15x1.40mm_HandSolder
D1, D2: LED; R_0805_2012Metric_Pad1.15x1.40mm_HandSolder
D3, D4: BAV99; SOT-23
J1: USB_A; PinHeader_1x05_P1.00mm_Vertical
J2: SD_Card; microSD_HC_Hirose_DM3D-SF
J3: USB_B_Mini; USB_Mini-B_Lumberg_2486_01_Horizontal
J4: SODIMM-200; Conn_TE-DDR2-SODIMM-0.6-200P-doublesided
J7: Conn_01x04_Male; PinSocket_1x04_P2.54mm_Vertical
JP1: Jumper_Boot_Select; PinSocket_1x03_P2.54mm_Vertical
JP2: WDT_S0; SolderJumper-3_P1.3mm_Open_RoundedPad1.0x1.5mm
JP3: WDT_S1; SolderJumper-3_P1.3mm_Open_RoundedPad1.0x1.5mm
JP4: WDT_S2; SolderJumper-3_P1.3mm_Open_RoundedPad1.0x1.5mm
Q1, Q2, Q3: BSS138; SOT-23
R1, R3, R6: 47K; R_0805_2012Metric_Pad1.15x1.40mm_HandSolder
R2, R7: 470R; R_0805_2012Metric_Pad1.15x1.40mm_HandSolder
R4, R5, R8, R9, R10, R11, R14, R15, R16: 100K; R_0805_2012Metric_Pad1.15x1.40mm_HandSolder
R12, R13: 4K7; R_0805_2012Metric_Pad1.15x1.40mm_HandSolder
R17, R19: 270R; R_0805_2012Metric_Pad1.15x1.40mm_HandSolder
R18, R20: 150R; R_0805_2012Metric_Pad1.15x1.40mm_HandSolder
U1: FSUSB42MUX; MSOP-10_3x3mm_P0.5mm
U2: TLV70218_SOT23-5; SOT-23-5
U3: MAX6373; SOT-23-8
U4: DS3231M; SOIC-16W_7.5x10.3mm_P1.27mm

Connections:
+1V8: C3.1, J4.183, J4.184, J4.185, J4.186, R4.1, U2.5 (OUT)
+5V: C1.1, C6.1, J1.1 (VBUS), J4.197, J4.198, J4.199, R5.2, U2.1 (IN); also elsewhere on the board
+5V_USB: J3.1 (VBUS), JP1.1 (A), Q3.1 (G), R6.1; also elsewhere on the board
/Audio_L: J4.70, R17.2
/Audio_R: J4.84, R11.1, R19.2
/EMMC_DISABLE_N: J4.2, Q1.3 (D)
/EMMC_EN_N_1V8: J4.90, Q2.1 (G), R4.2
/RTC_Int: J4.76, R15.2, U4.3 (~INT~/SQW)
/RTC_Rst: J4.78, R16.2, U4.4 (~RST)
/USB_DM: J4.167, U1.4 (D-)
/USB_DP: J4.165, U1.3 (D+)
ANT_RELEASE: J4.81; also elsewhere on the board
BATT_OFF: J4.63; also elsewhere on the board
CHG_INH: J4.75; also elsewhere on the board
EPS_EOC: J4.57; also elsewhere on the board
EPS_SPI_CLK: J4.35; also elsewhere on the board
EPS_SPI_CS: J4.27; also elsewhere on the board
EPS_SPI_MISO: J4.29; also elsewhere on the board
EPS_SPI_MOSI: J4.33; also elsewhere on the board
GPIO4: J4.15; also elsewhere on the board
GPIO5: J4.17; also elsewhere on the board
GPIO6: J4.21; also elsewhere on the board
GPIO7: J4.23; also elsewhere on the board
GPIO12: J4.45; also elsewhere on the board
GPIO13: J4.47; also elsewhere on the board
GPIO14: J4.51; also elsewhere on the board
GPIO15: J4.53; also elsewhere on the board
GPIO17: J4.59; also elsewhere on the board
GPIO19: J4.65; also elsewhere on the board
GPIO21: J4.71; also elsewhere on the board
GPIO23: J4.77; also elsewhere on the board
GPIO25: J4.83; also elsewhere on the board
GPIO26: J4.87; also elsewhere on the board
GPIO27: J4.89; also elsewhere on the board
unnamed: BT1.1 (+), U4.14 (VBAT)
unnamed: C2.1, R5.1, U2.3 (EN)
unnamed: C10.1, D3.1 (A), D3.2 (K), J7.1
unnamed: C10.2, C11.1, R17.1, R18.2
unnamed: C12.1, D4.1 (A), D4.2 (K), J7.3
unnamed: C12.2, C13.1, R19.1, R20.2
unnamed: D1.1 (K), Q1.2 (S), Q2.3 (D)
unnamed: D1.2 (A), R2.2
unnamed: D2.2 (A), R7.2
unnamed: J1.2 (D-), U1.8 (HSD2-)
unnamed: J1.3 (D+), U1.9 (HSD2+)
unnamed: J2.1 (CD/DAT3), J4.24
unnamed: J2.2 (CMD), J4.12
unnamed: J2.5 (CLK), J4.10
unnamed: J2.7 (DAT0), J4.16
unnamed: J2.8 (DAT1), J4.18
unnamed: J2.9 (DAT2), J4.22
unnamed: J3.2 (D-), U1.6 (HSD1-)
unnamed: J3.3 (D+), U1.7 (HSD1+)
unnamed: J4.28, R9.1
unnamed: J4.30, R8.1
unnamed: J4.82, R10.1
unnamed: J4.177, U3.7 (~WDO)
unnamed: JP1.2 (C), Q1.1 (G), R3.1
unnamed: JP2.2 (C), U3.4 (SET0)
unnamed: JP3.2 (C), U3.5 (SET1)
unnamed: JP4.2 (C), U3.6 (SET2)
unnamed: Q3.3 (D), R1.1, U1.2 (Sel)
unnamed: R14.2, U4.1 (32KHZ)
SCL1: J4.5, R12.2, U4.16 (SCL); also elsewhere on the board
SCL2: J4.11; also elsewhere on the board
SDA1: J4.3, R13.2, U4.15 (SDA); also elsewhere on the board
SDA2: J4.9; also elsewhere on the board
VBAT_SWITCH_EN: J4.69; also elsewhere on the board

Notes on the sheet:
GPIO0
GPIO1
GPIO2
GPIO3
GPIO4
GPIO5
GPIO6
GPIO7
GPIO8
GPIO9
GPIO10
GPIO11
GPIO0-27_VREF
GPIO28-45_VREF
GPIO12
GPIO13
GPIO14
GPIO15
GPIO16
GPIO17
GPIO18
GPIO19
GPIO20
GPIO21
GPIO22
GPIO23
GPIO24
GPIO25
GPIO26
GPIO27
DSIO_DN1
DSIO_DP1
DSIO_DN0
DSIO_DP0
DSIO_CN
DSIO_CP
USB_DP
USB_DM
RUN
VDD_CORE

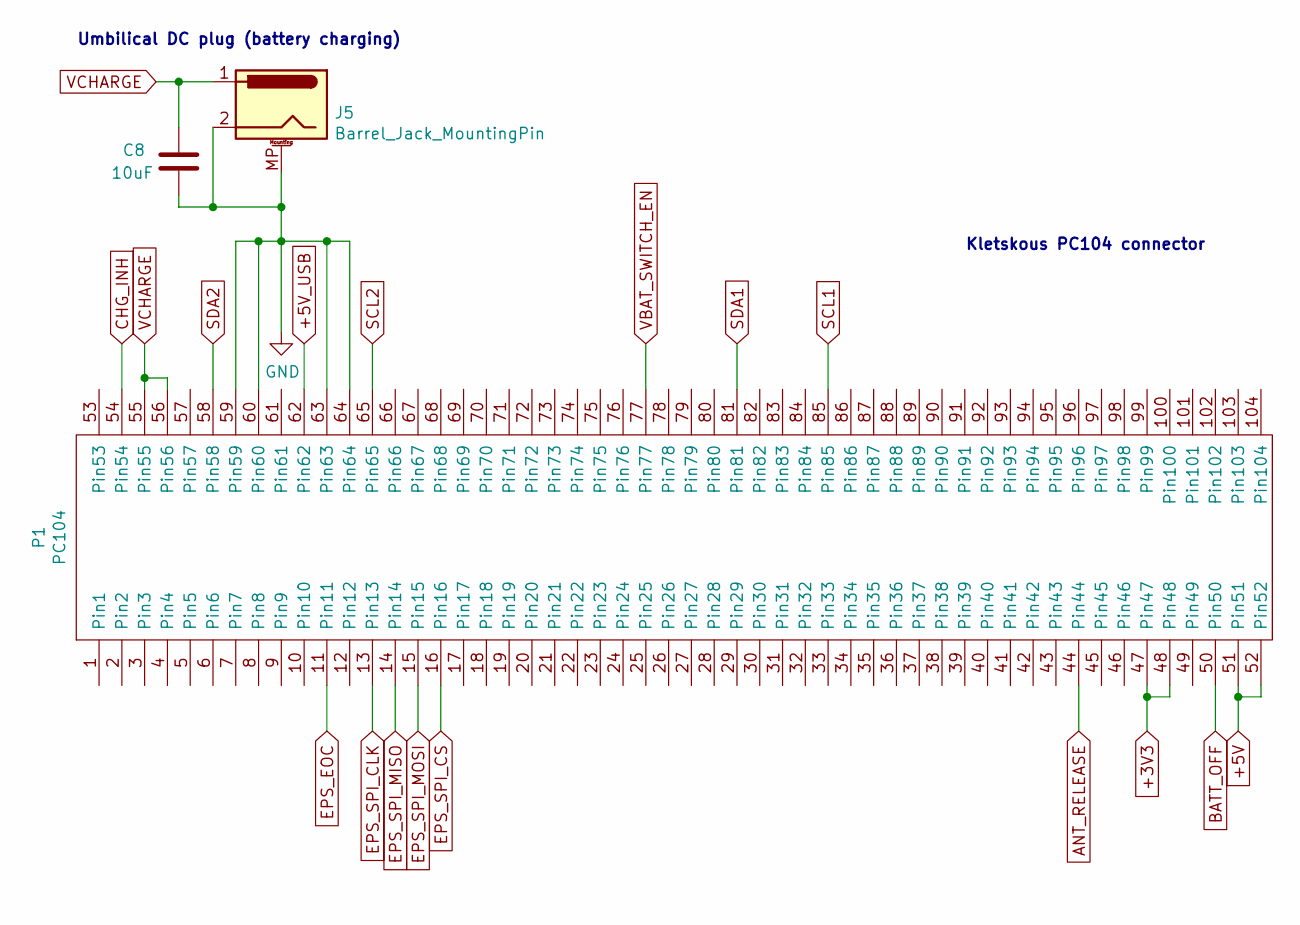
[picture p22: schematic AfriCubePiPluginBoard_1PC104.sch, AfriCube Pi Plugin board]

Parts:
C8: 10uF; R_0805_2012Metric_Pad1.15x1.40mm_HandSolder
J5: Barrel_Jack_MountingPin; BarrelJack_Wuerth_6941xx301002
P1: PC104

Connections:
+5V: P1.51 (Pin51), P1.52 (Pin52); also elsewhere on the board
+5V_USB: P1.62 (Pin62); also elsewhere on the board
ANT_RELEASE: P1.44 (Pin44); also elsewhere on the board
BATT_OFF: P1.50 (Pin50); also elsewhere on the board
CHG_INH: P1.54 (Pin54); also elsewhere on the board
EPS_EOC: P1.11 (Pin11); also elsewhere on the board
EPS_SPI_CLK: P1.13 (Pin13); also elsewhere on the board
EPS_SPI_CS: P1.16 (Pin16); also elsewhere on the board
EPS_SPI_MISO: P1.14 (Pin14); also elsewhere on the board
EPS_SPI_MOSI: P1.15 (Pin15); also elsewhere on the board
SCL1: P1.85 (Pin85); also elsewhere on the board
SCL2: P1.65 (Pin65); also elsewhere on the board
SDA1: P1.81 (Pin81); also elsewhere on the board
SDA2: P1.58 (Pin58); also elsewhere on the board
VBAT_SWITCH_EN: P1.77 (Pin77); also elsewhere on the board
VCHARGE: C8.1, J5.1, P1.55 (Pin55), P1.56 (Pin56)

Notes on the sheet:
Kletskous PC104 connector
Umbilical DC plug (battery charging)

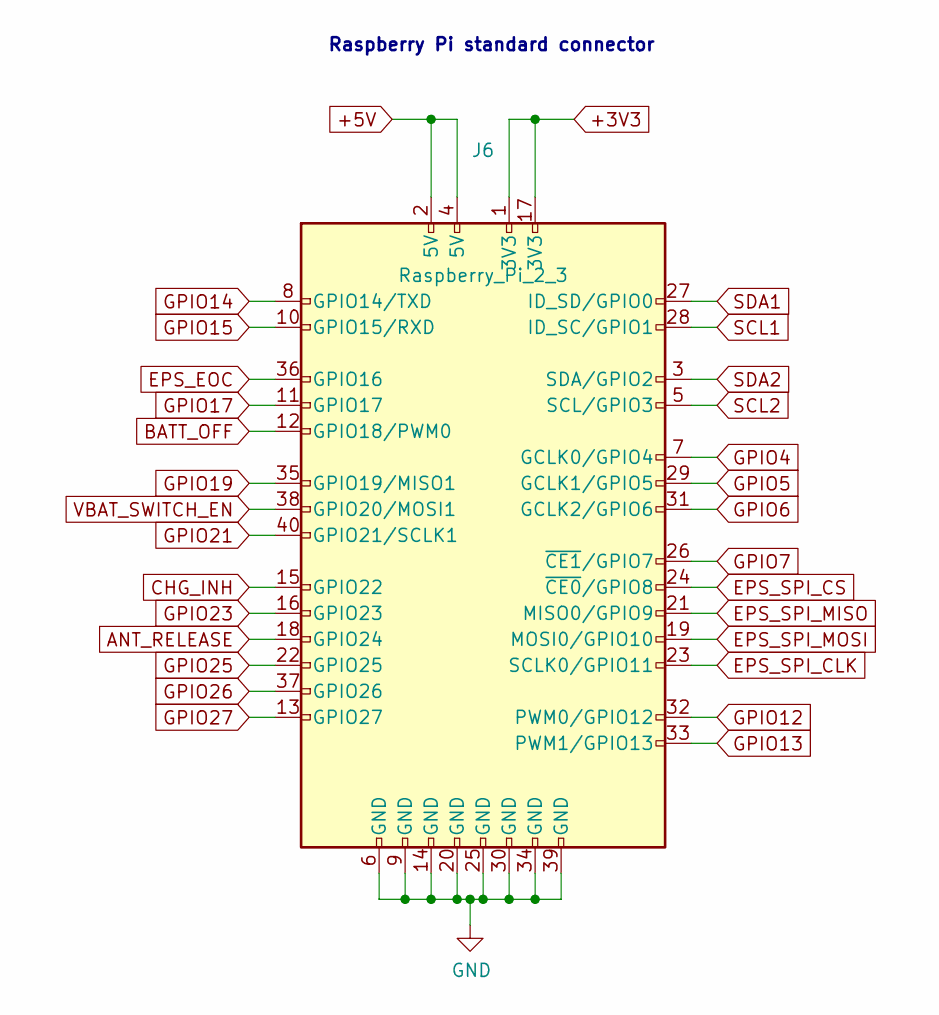
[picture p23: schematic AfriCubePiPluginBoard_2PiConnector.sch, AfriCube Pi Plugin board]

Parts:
J6: Raspberry_Pi_2_3; PinHeader_2x20_P2.54mm_Vertical

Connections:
+5V: J6.2 (5V), J6.4 (5V); also elsewhere on the board
ANT_RELEASE: J6.18 (GPIO24); also elsewhere on the board
BATT_OFF: J6.12 (GPIO18/PWM0); also elsewhere on the board
CHG_INH: J6.15 (GPIO22); also elsewhere on the board
EPS_EOC: J6.36 (GPIO16); also elsewhere on the board
EPS_SPI_CLK: J6.23 (SCLK0/GPIO11); also elsewhere on the board
EPS_SPI_CS: J6.24 (~CE0~/GPIO8); also elsewhere on the board
EPS_SPI_MISO: J6.21 (MISO0/GPIO9); also elsewhere on the board
EPS_SPI_MOSI: J6.19 (MOSI0/GPIO10); also elsewhere on the board
GPIO4: J6.7 (GCLK0/GPIO4); also elsewhere on the board
GPIO5: J6.29 (GCLK1/GPIO5); also elsewhere on the board
GPIO6: J6.31 (GCLK2/GPIO6); also elsewhere on the board
GPIO7: J6.26 (~CE1~/GPIO7); also elsewhere on the board
GPIO12: J6.32 (PWM0/GPIO12); also elsewhere on the board
GPIO13: J6.33 (PWM1/GPIO13); also elsewhere on the board
GPIO14: J6.8 (GPIO14/TXD); also elsewhere on the board
GPIO15: J6.10 (GPIO15/RXD); also elsewhere on the board
GPIO17: J6.11 (GPIO17); also elsewhere on the board
GPIO19: J6.35 (GPIO19/MISO1); also elsewhere on the board
GPIO21: J6.40 (GPIO21/SCLK1); also elsewhere on the board
GPIO23: J6.16 (GPIO23); also elsewhere on the board
GPIO25: J6.22 (GPIO25); also elsewhere on the board
GPIO26: J6.37 (GPIO26); also elsewhere on the board
GPIO27: J6.13 (GPIO27); also elsewhere on the board
SCL1: J6.28 (ID_SC/GPIO1); also elsewhere on the board
SCL2: J6.5 (SCL/GPIO3); also elsewhere on the board
SDA1: J6.27 (ID_SD/GPIO0); also elsewhere on the board
SDA2: J6.3 (SDA/GPIO2); also elsewhere on the board
VBAT_SWITCH_EN: J6.38 (GPIO20/MOSI1); also elsewhere on the board

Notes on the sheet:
Raspberry Pi standard connector

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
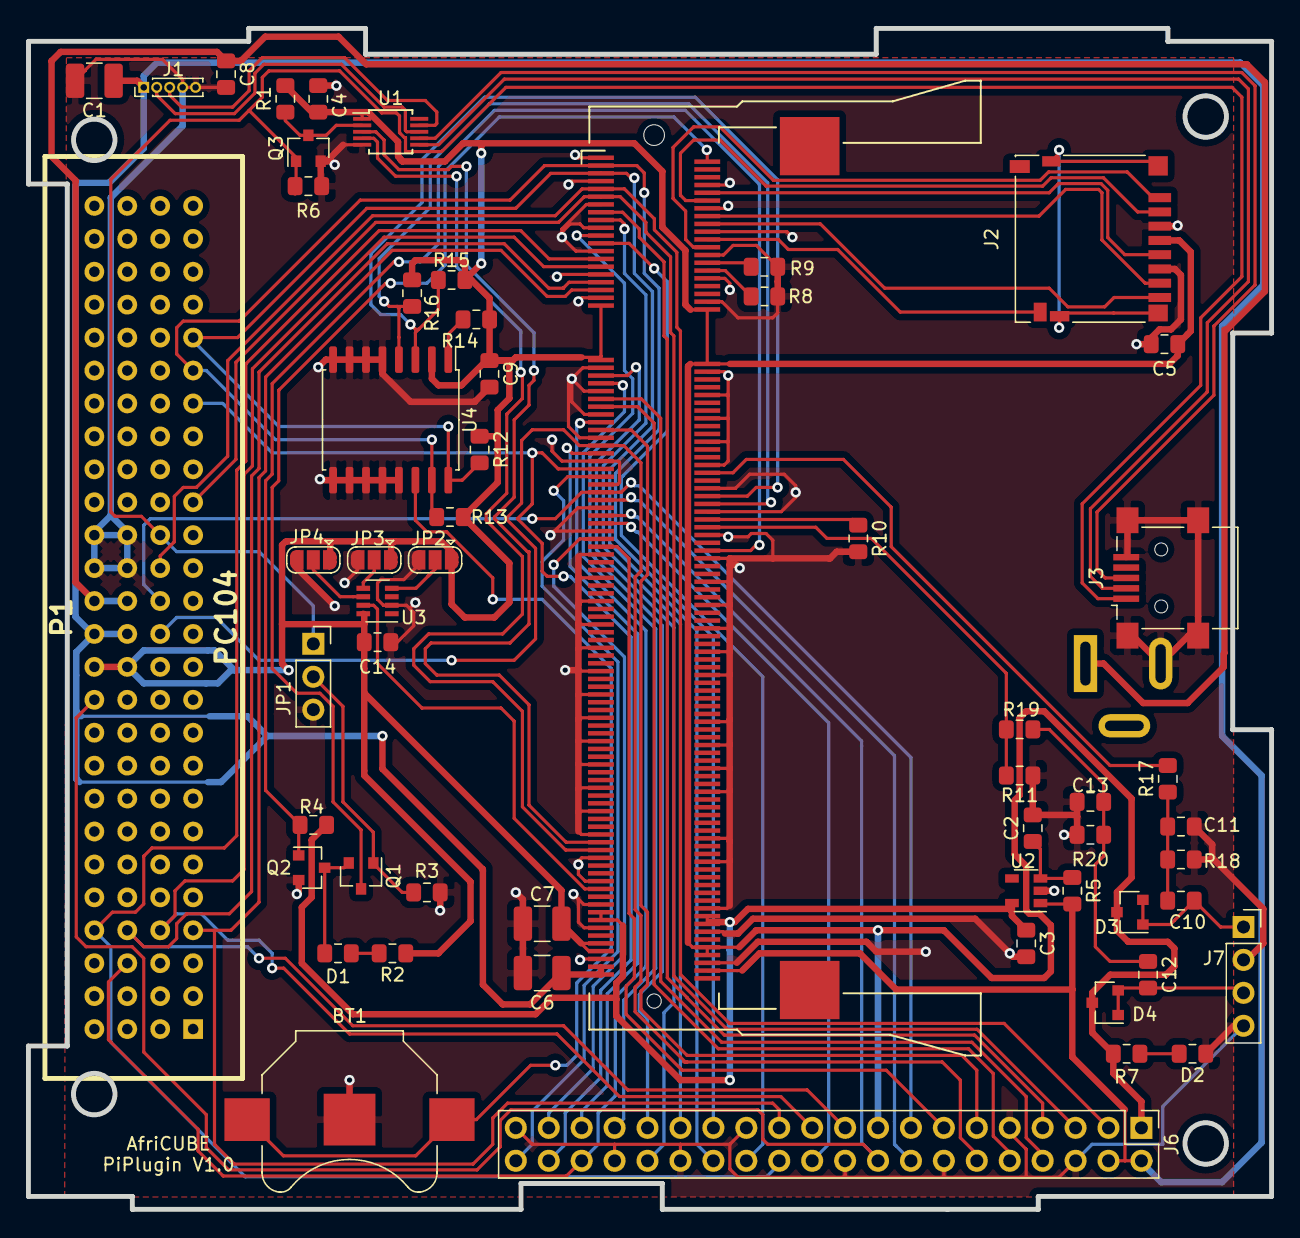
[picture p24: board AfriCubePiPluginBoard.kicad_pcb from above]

Board: 2 copper layers, 95.9 x 91.1 mm, 58 parts (1 on the bottom side), 71 nets.

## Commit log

2021-02-03 version 1.0_of RX board
    [AfriCubePiPluginBoard-B_Adhes.gbr, AfriCubePiPluginBoard-B_Cu.gbr, AfriCubePiPluginBoard-B_Mask.gbr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]
2021-02-03 adding board picture
2021-02-28 adding v2 2 filter front end filter
    [misc.sch, msi001.sch, msi2500.sch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]
2022-05-18 adding second filter from shaun
    [msisdr.kicad_pcb]
